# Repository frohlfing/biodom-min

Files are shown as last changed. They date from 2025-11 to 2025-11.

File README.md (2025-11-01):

# Projekt "Biodom Mini" – Ein Hightech-Gewächshaus

Das Ziel ist ein Mini-Gewächshaus für anspruchsvolle Pflanzen, das automatisch für ein tropisches Klima sorgt.

**Features:**

- Künstliche Sonne
- Konstante Temperatur
- Konstante Luftfeuchtigkeit
- Automatische Bewässerung
- Kamera (schießt ein Bild pro Tag für Zeitraffer-Video)
- Display (zeigt aktuelle Werte an)
- Webinterface (über WLAN erreichbar)

## Projektdokumentation

Eine detailliertere technische Dokumentation befindet sich in [Projektdokumentation.md](docs/Projektdokumentation.md).

## Lizenz

Dieses Projekt steht unter der [GPL-3.0-Lizenz](LICENSE).

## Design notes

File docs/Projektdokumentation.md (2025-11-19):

# Projekt "Biodom Mini" – Ein Hightech-Gewächshaus

* **Version:** 1.0.2
* **Datum:** 11.11.2025
* **Autor:** Frank Rohlfing

Das Ziel ist ein Mini-Gewächshaus für anspruchsvolle Pflanzen, das automatisch für ein tropisches Klima sorgt.

**Features:**

- Künstliche Sonne
- Konstante Temperatur
- Konstante Luftfeuchtigkeit
- Automatische Bewässerung
- Kamera (schießt ein Bild pro Tag für Zeitraffer-Video)
- Display (zeigt aktuelle Werte an)
- Webinterface (über WLAN erreichbar)

**Inhaltsverzeichnis**

* [Projekt "Biodom Mini" – Ein Hightech-Gewächshaus](#projekt-biodom-mini--ein-hightech-gewächshaus)
  * [1. Gehäuse](#1-gehäuse)
  * [2. Steuereinheit](#2-steuereinheit)
  * [3. Sensoren](#3-sensoren)
  * [4. Aktoren](#4-aktoren)
  * [5. Sonstige Peripheriegeräte](#5-sonstige-peripheriegeräte)
  * [6. Stromversorgung](#6-stromversorgung)
  * [7. Schaltplan](#7-schaltplan)
  * [8. Programmierung](#8-programmierung)

  * [Anhang](#anhang)

## 1. Gehäuse

### Gewächshaus 

AKERBÄR Gewächshaus 65, anthrazit

[Ikea](https://www.ikea.com/de/de/p/akerbaer-gewaechshaus-drinnen-draussen-anthrazit-20537175/)
29,99 €

Gewächshaus

Maße Gewächshaus

Maße: 65 x 22 (bzw. 13 oben) x 40 cm (B, T, H) 

### Blumenkasten 

Geli Blumenkasten Standard 60 cm

[Obi](https://www.obi.de/p/7331374/geli-blumenkasten-standard-ca-60-cm-anthrazit)
1,65 €

Blumenkasten

Maße: 60 x 18 x 13,7 cm (B, T, H)	

### Behälter für den Teich

Bedingungen: 
* Der Behälter muss eine grade Wand haben, um den Füllstandsensor anbringen zu können.
* Das Material darf aufgrund des Füllstandsensors nicht aus Metall sein (Glas, Kunststoff oder Keramik ist ok).
* Muss in den Blumenkasten passen (max. 12 cm tief, 13 cm hoch).

Ich habe diese Vase im Keller gefunden, passt perfekt:

* Material: Glas
* Außenmaße: 10 x 10 x 10 cm  
* Wandstärke: 4mm

### Bewässerungsset

Bewässerungsschlauch 4/6 mm (passend zur Wasserpumpe)

Bewässerungsset
Bewässerungsset

[Amazon](https://www.amazon.de/gp/product/B0DSP1KB8S)
7,98 €; "Einzelpreis": 3,99 €		

5 m Schlauch, 10 Tropf-Sprinkler, 2 Ventile, Verbinder (reicht locker für 2 Häuschen)

### Elektronik-Box

Kunststoffgehäuse 200 x 120 x 75 mm

Kunststoffgehäuse

[Amazon](https://www.amazon.de/dp/B0DJD3WC1V)
7,99 €

* IP65 (wasserdicht)

In das Gehäuse wird das Mainboard geschraubt. 

### Mainboard

Lochrasterplatine, 160 x 100 mm, blau 

Standard-Platine

[Amazon](https://www.amazon.de/gp/product/B081K7467B)
7,99 €

* Durchkontaktiert, runde Pads
* Rastermaß: 2,54 mm
* 1,6 mm dick

### Klinkenstecker und -Buchsen für die Sensoren (Kamera ausgenommen)

3.5 mm Stereo-Klinkenstecker und -Buchse 

Klinkenstecker und -Buchse

https://www.amazon.de/dp/B09TK2HNKD
6,79 € (10 Stück)

* Muss Stereo sein (3 Pins)!

4 Klinkenbuchsen werden benötigt für:
* Luft
* Bodentemperatur
* Bodenfeuchte
* Wasserstand

**Pinbelegung:**!

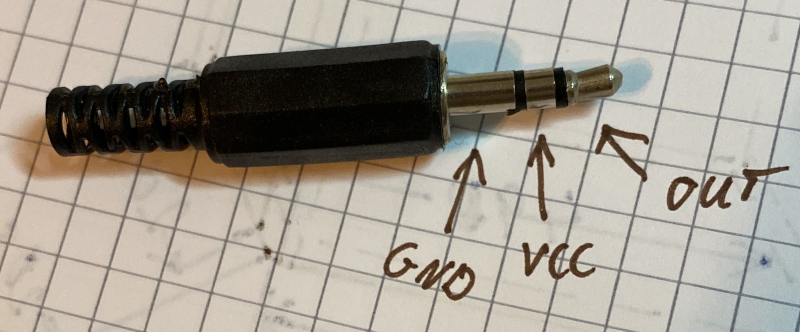
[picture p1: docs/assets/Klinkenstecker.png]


### Hohlstecker und -Buchen für die Aktoren und Stromversorgung

DC Power Jack Buchse und Stecker, 2.1 mm, 2 Polig 

Auch DC-Stecker und DC-Buchse genannt.

DC Buchse

[Amazon](https://www.amazon.de/dp/B07QNWSKN2)
7,49 € (12 Stück)

* Typ: 5.5 x 2.1 mm Buchse (passend zum 5.5x2.1 mm Holstecker des Netzteils)

7 Hohlstecker-Buchsen werden benötigt für:
* Lampe 1
* Lampe 2
* Heizer
* Dunst
* Pumpe
* Lüfter
* DC 12V

**Pinbelegung:**!

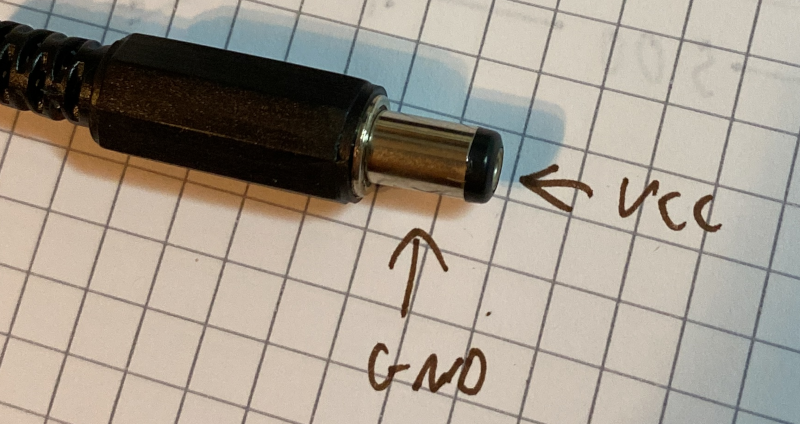
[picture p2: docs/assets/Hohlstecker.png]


### Sonstiges Zubehör

**Stiftleisten und Buchsenleisten zum Einlöten auf die Platine** 

Auch unter "Pinheader" zu finden.

  Stift- und Buchenleisten

  [Amazon](https://www.amazon.de/dp/B0BZH6YZF8)
  10,99 €

**Kabelschlauch, selbstschließend**

Kabelschlauch

6 mm Durchmesser, 3 m: 
[Amazon](https://www.amazon.de/dp/B07FW5H57B)
7,99 €

13 mm Durchmesser, 3 m: 
[Amazon](https://www.amazon.de/dp/B07FW3GTXB)
7,99 €

**Abstandhalter Set**

Abstandhalter

[Amazon](https://www.amazon.de/dp/B0DCS5C7SN)
8,99 €

**Schraubklemmen Set**
Schraubklemmen
[Amazon](https://www.amazon.de/dp/B082ZNRQMJ)
8,99 €

## 2. Steuereinheit

### Mikrocontroller

ESP32-DevKitC V2

ESP32-DevKitC V2

[Amazon](https://www.amazon.de/dp/B074RGW2VQ)
10,99 €

[AZ-Delivery e-Book](https://cdn.shopify.com/s/files/1/1509/1638/files/AZ281_A_18-10_DE_B08BTWJGFX_e699c448-ffc6-4744-8b93-5c9f102d22b0.pdf),  
[Espressif Doku](https://docs.platformio.org/en/latest/boards/espressif32/esp32-c3-devkitc-02.html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),  
[Datasheet](https://cdn.shopify.com/s/files/1/1509/1638/files/ESP_-_32_NodeMCU_Developmentboard_Datenblatt_AZ-Delivery_Vertriebs_GmbH_10f68f6c-a9bb-49c6-a825-07979441739f.pdf)

* Micro-USB-Anschluss
* 38-Pin
* ESP32-WROOM-32-Chip
* CP2102

**Anmerkung:**

Das Modell mit UCD-C macht nur Probleme. Keins meiner UCB-C-Kabel hat funktioniert.

**Pinbelegung:**
<pre>  
                                       ┌────────────────┐
                           +3.3V Out ──┤ 3V3 ESP32  GND ├── GND
                                     ──┤ EN  DevKit G23 ├── GPIO23 SPI_MOSI ──► Kamera + SD-Karte
  Reserve analog./dgl. In ──► GPIO36 ──┤ SP  C V2   G22 ├── GPIO22 I2C_SCL  ──► Kamera + Display + Lichtstärke
       (frei analog./dgl. In) GPIO39 ──┤ SN         TXD ├── GPIO1  (UART0_TX)
    Bodenfeuchte (analog) ──► GPIO34 ──┤ G34        RXD ├── GPIO3  (UART0_RX)
              Wasserstand ──► GPIO35 ──┤ G35        G21 ├── GPIO21 I2C_SDA  ◄─► Kamera + Display + Lichtstärke
         Dunst Relais IN7 ◄── GPIO32 ──┤ G32        GND ├── GND
         Pumpe Relais IN6 ◄── GPIO33 ──┤ G33        G19 ├── GPIO19 SPI_MISO ◄── Kamera + SD-Karte
        Lüfter Relais IN5 ◄── GPIO25 ──┤ G25        G18 ├── GPIO18 SPI_CLK  ──► Kamera + SD-Karte
        Heizer Relais IN4 ◄── GPIO26 ──┤ G26         G5 ├── ──► LED
       Lampe-2 Relais IN3 ◄── GPIO27 ──┤ G27        G17 ├── GPIO17 SPI_CS   ──► Kamera
       Lampe-1 Relais IN2 ◄── GPIO14 ──┤ G14        G16 ├── GPIO16 SPI_CS   ──► SD-Karte
                        (frei, Boot) ──┤ G12         G4 ├── GPIO4           ◄─► Bodentemperatur (One-Wire)
                                 GND ──┤ GND         G0 ├── (frei, Boot)
  Luft (One-Wire-ähnlich) ◄─► GPIO13 ──┤ G13         G2 ├── (frei, Boot)
                                     ──┤ SD2        G15 ├── (frei, Boot)
                                     ──┤ SD3        SD1 ├──
                                     ──┤ CMD        SD0 ├──
                              +5V in ──┤ 5V  [USB]  CLK ├──
                                       └────────────────┘
</pre>

### Relais-Modul

8-Relais-Modul mit Optokoppler, 5V 

Relais
Relais Anschlüsse

[Amazon](https://www.amazon.de/dp/B07CT7SLYQ)
9,59 €

[AZ-Delivery e-Book](https://cdn.shopify.com/s/files/1/1509/1638/files/AZ041_C_9-7_DE_B07CT7SLYQ_b3af212d-3531-46ad-b4fc-e49166c8d2f2.pdf),
[Datasheet](https://cdn.shopify.com/s/files/1/1509/1638/files/8-Relais_Modul_Datenblatt_AZ-Delivery_Vertriebs_GmbH_1f00ff0d-33ca-4546-9ddc-7b2c223f5aa3.pdf)

* Max. DC:  5A, 30V pro Relais
* Maße: 50 x 140 mm

**Anmerkung:**

* Der Jumper zwischen VCC und JD-VCC muss gesteckt sein, da die Relais-Spulen auch von Steuerstromkreis versorgt werden sollen. Ein Stützkondensator wird die Induktionsspitzen beim Schalten abfangen.
* **Achtung, invertierte Logik**: Mit LOW wird das Relais geschaltet, nicht mit HIGH!

**Pinbelegung:**

**Achtung:** Die Pinbelegung sowohl im E-Book und als auch im Datasheet ist nicht korrekt abgebildet: 
NC und NO sind vertauscht. Die Symbole auf dem Modul sind korrekt, sowie hier:

<pre>
         ┌────────────────┐
         │ 8 Relay    NC1 ├──  
         │ Module    Com1 ├──
         │            NO1 ├──
         │            NC2 ├──
         │           Com2 ├── +12V        GND ─O──(schwarz)── GND
         │            NO2 ├────────────────────O──(rot)────── A1: Lampe 1
   GND ──┤ GND        NC3 ├──   
       ─►┤ IN1       Com3 ├── +12V        GND ─O──(schwarz)── GND
GPIO14 ─►┤ IN2        NO3 ├────────────────────O──(rot)────── A2: Lampe 2
GPIO27 ─►┤ IN3        NC4 ├──
GPIO26 ─►┤ IN4       Com4 ├── +12V        GND ─O──(schwarz)── GND
GPIO25 ─►┤ IN5        NO4 ├────────────────────O──(rot)────── A3: Heizer
GPIO33 ─►┤ IN6        NC5 ├──
GPIO32 ──┤ IN7       Com5 ├── +12V        GND ─O──(schwarz)── GND
       ──┤ IN8        NO5 ├────────────────────O──(rot)────── A4: Lüfter
   +5V ──┤ VCC        NC6 ├──
         │           Com6 ├── +12V         GND ─O──(schwarz)── GND
         │            NO6 ├────────────────────O──(rot)────── A5: Pumpe  
         │            NC7 ├──
         │           Com7 ├── +5V        GND ─O──(schwarz)── GND
       ──┤ GND        NO7 ├────────────────────O──(rot)────── A6: Dunst
   Jum- ┌┤ VCC        NC8 ├──  
   per  └┤ JD-VCC    Com8 ├──
         │            NO8 ├──
         └────────────────┘
</pre>

## 3. Sensoren

### S1: Luft (Raumtemperatur und Luftfeuchtigkeit)

Raumtemperatur- und Luftfeuchtigkeitssensormodul AM2302, auch bekannt als DHT22.

Tatsächlich ist AM2302 ein Nachfolgemodel von DHT22 und präziser. 

Der Sensor ist auch "pur" ohne Modul erhältlich. Dann muss zusätzlich ein Pullup-Widerstand (typischerweise 4.7 kΩ bis 10 kΩ) zwischen der Datenleitung und VCC angeschlossen werden. Ich verwende hier das Modul, das den Pullup-Widerstand bereits beinhaltet.

AM2302

[Amazon](https://www.amazon.de/dp/B078SVZB1X)
8,49 €

[AZ-Delivery e-Book](https://cdn.shopify.com/s/files/1/1509/1638/files/AZ073_A10-7_DE_B06XF4TNT9_a2f405a2-b242-44dc-aa26-428bc637eef5.pdf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),
[Datasheet](https://www.makerguides.com/wp-content/uploads/2019/02/DHT22-AM2302-Datasheet.pdf)

**Anmerkung:**

* Das Protokoll für den AM2302ist (One-Wire) ist bidirektional. Demnach darf dieser Sensor nicht an die GPIO 34, 35, 36 oder 39!
* Bei einer Versorgungsspannung von 3.3V darf die Kabellänge nicht größer als 1 Meter sein.

**Pinout:**

| Pin | Bezeichnung | Farbe | Beschreibung |
|-----|---|---|---|
| 1 | + | rot | 3.3V - 5.5V  |  
| 2 | Out | gelb | Daten-Pin |  
| 3 | - | schwarz  | GND | 

**Pinbelegung:**
<pre>
┌────────────────┐
│ AM2302       - ├──(schwarz)─O─── GND 
│ Module     Out ├─────(gelb)─O─►─ GPIO13
│              + ├─►────(rot)─O─── +3.3V
└────────────────┘               
</pre>

**Benötigte Bibliothek:**

* SimpleDHT 1.0.15 by Winlin

### S2: Bodentemperatur

Bodentemperatursensor DS18B20

Dieser Sensor ist wasserdicht, kommt mit 1m-Kabel und Edelstahlhülse.

DS18B20

[Amazon](https://www.amazon.de/dp/B01MZG48OE)
8,29 €	(2 Stück); Einzelpreis: 4,15 €

[AZ-Delivery e-Book](https://cdn.shopify.com/s/files/1/1509/1638/files/AZ079_C_12-8_DE_B01MZG48OE_249c2b9f-7891-4e9a-9169-0dc281f12f11.pdf),
[Datasheet](https://cdn.shopify.com/s/files/1/1509/1638/files/DS18B20_1mCable_datasheet.pdf)

**Anmerkung:**

Das Protokoll für den DS18B20 (One-Wire) ist bidirektional. Demnach darf dieser Sensor nicht an die GPIO 34, 35, 36 oder 39!

**Pinout:**

| Pin  | Bezeichnung | Farbe | Beschreibung |
|---|---|---|---|
| 1 | VCC | rot | 3.3 - 5.5V |  
| 2 | DATA | gelb | Daten-Pin | 
| 3 | GND | schwarz | GND |

**Pull-Up-Widerstand R1 = 4.7 kΩ** 

Wird zwischen dem roten Kabel (VCC) und dem gelben Kabel (DATA) an die Buchsenleiste gelötet.

**Pinbelegung mit Pullup-Widerstand:**
<pre>
┌────────────────┐                   R1=4.7k
│ DS18B20    GND ├──(schwarz)─O────────────────── GND 
│           DATA ├─────(gelb)─O─────┬───────────► GPIO4
│            VCC ├─►────(rot)─O──┐  └─[ R1 ]─┐
└────────────────┘               └───────────┴─── +3.3V
</pre>

**Benötigte Bibliothek:**

* DallasTemperature 4.0.5 by Miles Burton

### S3: Bodenfeuchte

Kapazitiver Bodenfeuchtigkeitssensor v1.2

Auch bekannt als "Capacitive Soil Moisture Sensor v1.2" oder "Hygrometer Module v1.2".

Hygrometer

[Amazon](https://www.amazon.de/dp/B07HJ6N1S4)
6,46 €

[Praxisbericht](https://www.makerguides.com/capacitive-soil-moisture-sensor-with-arduino/), 
[AZ-Delivery e-Book](https://cdn.shopify.com/s/files/1/1509/1638/files/AZ063_A_16-13_DE_B07HJ6N1S4_1746d1f6-6b82-4b8a-bee1-88d83344cb5a.pdf),
[Datasheet](https://cdn.shopify.com/s/files/1/1509/1638/files/Hygrometer_V1.2_Sensor_Modul_Datenblatt_AZ-Delivery_Vertriebs_GmbH.pdf)

* 5V (!)
* Größe: 22 x 97 x 9 mm 
* analoger Ausgang 

**Anmerkung:** 

[Paradisetronic.com](https://www.amazon.de/dp/B08944FNXV) bietet den Sensor für 3.3V an. Dazu müsste aber ein TLC555C oder TLC555I verbaut sein. 
Tatsächlich ist wie bei AZDelivery ein NE555 drauf (minimale Versorgungsspannung von 4.5V lt. Datenblatt). 
Damit ist der Betrieb mit 3.3V nicht möglich oder zumindest kritisch (s. Praxisbericht oder [Kundenrezension](https://www.amazon.de/gp/customer-reviews/R2E7NX4GYVWY0/ref=cm_cr_getr_d_rvw_ttl?ie=UTF8)). 

**Pinout:**

| Pin  | Bezeichnung | Farbe | Beschreibung |
|---|---|---|---|
| 1 | GND | schwarz | GND |  
| 2 | VCC | rot | 5V | 
| 3 | AOUT | gelb | Daten-Pin |

**Anmerkung:**

Der Sensor hat eine Betriebsspannung von 5 V. Die maximale Ausgangsspannung liegt aber deutlich unter 3.3 V. Ein Spannungsteiler ist also nicht erforderlich.

**Pinbelegung:**
<pre>
┌─────────────────┐
│ Capacitive  GND ├──(schwarz)─O─── GND 
│ Hygrometer  VCC ├──────(rot)─O─── +5V
│ v1.2       AOUT ├─►───(gelb)─O─►─ GPIO34
└─────────────────┘
</pre>   

**Messbereich:**

Darüber steht nichts im Datenblatt. Die Werte habe ich experimental ermittelt.

* Komplett trocken (in der Luft): 2080 mV
* Komplett feucht (im Wasser): 800 mV 

**Benötigte Bibliothek:**

(keine Abhängigkeiten)

**Kalibrierung:**

* Weiße Markierung für die Einstecktiefe beachten!

Messung der Rohwerte: 
```
void setup() {
  Serial.begin(115200);  
}

int valMax = 0;
int valMin = 99999; 

void loop() {
  int val = analogRead(34);  
  if (val < valMin) {
    valMin = val;
  }
  if (val > valMax) {
    valMax = val;
  }
  Serial.print("Min:");
  Serial.print(valMin);
  Serial.print(",Max:");
  Serial.print(valMax);
  Serial.print(",Curr:");
  Serial.println(val);
  delay(1000);
}
``` 
 
Die Messung ergibt 
* im Wasser: 995 bis 1055 => unter 1100
* in der Luft: 2642 bis 2734 => über 2500

Der folgende Code verwendet die Rohwerte und ordnet sie einem Bereich von 0 bis 100 % zu:

```
const int valWater = 1100;
const int valAir = 2500;

void setup() {
  Serial.begin(115200);
}

void loop() {
  int val = analogRead(34);
  int percent = map(val, valAir, valWater, 0, 100);
  percent = constrain(percent, 0, 100);
  Serial.println(percent);
  delay(1000);
}
```

### S4: Wasserstand

Berührungsloser Füllstandsensor XKC-Y25-NPN 

XKC-Y25-NPN

[Amazon](https://www.amazon.de/dp/B0C1ZVZF2L)
10,19 €

[Tutorial](https://www.kreativekiste.de/arduino-anschluss-fluessigkeitsstandsensor-xkc-y25-pnp-sps), 
[Datasheet](https://www.nuggetforum.de/media/kunena/attachments/23214/NPN-bb00ea11-07b9-4b43-be78-ce18f0e40b48.pdf)
 
* 5-12 V, 100 mA
* berührungslos, kann Kunststoff-, Glas-, Keramik- und andere nichtmetallische Behälter durchdringen (≤ 20 mm dick)
* wasserdicht
* Ausgang: NPN, digital (LOW bei Wassererkennung)
* Kabellänge: ca. 50 cm
* Pegelfehler: ±1,5 mm

**Pinout:**

| Pin | Bezeichnung | Farbe am Sensor | Farbe am Klinkenstecker | Beschreibung |
|-----|---|---|---|---|
| 1 | VCC | braun | rot | Versorgung (5–12V) |  
| 2 | OUT | gelb | grün | Digitaler Ausgang | 
| 3 | GND | blau | weiß | GND |
| 4 | MODE | schwarz | - | Modus-Umschaltung (wird nicht benötigt)  | 

**Anmerkung:**

* Eventuell sind Schwarz und Gelb vertauscht (OUT = Schwarz, MODE = Gelb)

Pegel am Ausgang:

* Der Sensor wird mit 5 V versorgt, aber das ist in diesem Fall kein Problem für den ESP32. 
	Denn am Ausgang liegen niemals die +5V an: 
	* Wasser erkannt: Er verbindet seinen Ausgang (OUT) mit GND.
	* Kein Wasser: Der Ausgang ist hochohmig (existiert quasi nicht).

**Pull-Up-Widerstand R2 = 10 kΩ**

Wird zwischen +3.3V vom ESP32 und dem gelben Kabel (OUT) an die Buchsenleiste gelötet.

So wird der Pegel auf HIGH (+3.3V) gezogen, wenn Trockenheit erkannt wird.    

**Pinbelegung mit Pullup-Widerstand:**
<pre>
┌────────────────┐                     R2=10k 
│ XKC-Y25    VCC ├────(braun)─O───────────────── +5V   
│ -NPN       OUT ├─►───(gelb)─O─────┬──[ R2 ]─── +3.3V 
│            GND ├─────(blau)─O───┐ └─────────►─ GPIO35    
│           MODE ├──(schwarz)─O   └───────────── GND         
└────────────────┘    
</pre>

**Benötigte Bibliothek:**

(keine Abhängigkeiten)

### S5: Lichtstärke

Lichtsensormodul GY-302 BH1750

Dieser Sensor ist sehr genau und misst das Licht direkt in LUX.

GY-302 BH1750

[Amazon](https://www.amazon.de/dp/B07TKWNGZ4)
5,49 €

[AZ-Delivery e-Book](https://cdn.shopify.com/s/files/1/1509/1638/files/AZ104_A6-9_DE_B07TKWNGZ4.pdf)
[Datasheet](https://cdn.shopify.com/s/files/1/1509/1638/files/GY-302_Licht_Sensor_Modul_Datenblatt_AZ-Delivery_Vertriebs_GmbH.pdf)

* I2C-Schnittstelle (Adresse 0x23 (oder 0x5C, wenn der ADDR-Pin auf HIGH gelegt wird))
* Der IC auf der Platine direkt über dem Schriftzug "BH1750" ist das lichtempfindliche Bauteil. 
**Pinout:**

| Pin | Bezeichnung | Farbe | Beschreibung |
|-----|---|---|---|
| 1 | VCC | rot | 3.3V, 5V |  
| 2 | GND | schwarz | GND | 
| 3 | SCL | braun | I2C Serial Clock (input) | 
| 4 | SDA | orange  | I2C Serial Data (bidirectional) |  
| 5 | ADDR | gelb | Geräteadresse (input) |  

**Pinbelegung:**
<pre>
┌────────────────┐
│ GY-302     VDD ├──────(rot)─O── +3.3V
│ BH1750     GND ├──(schwarz)─O── GND
│            SCL ├────(braun)─O─◄─ GPIO22
│            SDA ├───(orange)─O◄─► GPIO21 
│           ADDR ├─────(gelb)─O──
└────────────────┘
</pre>

**Anmerkung:**

Da kein anderes I2C-Gerät die Adresse 0x23 verwendet, wird ADDR nicht benötigt.

**Benötigte Bibliothek:**

* BH1750 1.3.0 by Christofer Laws

### S6: Reserve

Der Analog-/Digitaleingang GPIO36 wird über eine Stiftleiste zugänglich gemacht. Er ist noch nicht verplant.

Als Beispiel könnte ein Fotowiderstand (auch Fotozelle oder LDR (Licht-Dependent Resistor) genannt) angeschlossen werden:

Fotowiderstand LDR5528

[Amazon](https://www.amazon.de/dp/B089YNCYG4)
4,49 € (10 Stück), Einzelpreis: 0,49 €

[AZ-Delivery e-Book](https://cdn.shopify.com/s/files/1/1509/1638/files/AZ098_B_16-1_DE_B089YNCYG4_ff124573-82f8-46ba-8411-8660b6462697.pdf)
[Datasheet](https://cdn.shopify.com/s/files/1/1509/1638/files/Fotowiderstand_Photo_Resistor_Dioden_150V_5mm_LDR5528_GL5528_5528_Datenblatt_AZ-Delivery_Vertriebs_GmbH.pdf)

5mm
* 0.5 - 200 kΩ
* Maximale Spannung: 150 V
* Maximale Leistung: 100 mW

Der Fotowiderstand ist lichtabhängig. Je mehr Licht auf die Oberfläche fällt, desto geringer ist sein Widerstand.

Der Sensor wird zusammen mit einem Widerstand als Spannungsteiler an einem analogen Eingang des ESP32 geschaltet. 
Dieser wandelt die Spannung in ganzzahlige Werte zw. 0 (dunkel) und 4049 (hell) um, die als ADC-Wert oder Analogwert bezeichnet werden.

<pre>
                    ↙↙
GND ───[ R3 ]──┬──[ LDR ]──── +3.3V
        10 kΩ  │  LDR5528
               └───────────►─ GPIO36
</pre>

**Benötigte Bibliothek:**

(keine Abhängigkeiten)

## 4. Aktoren

### A1, A2: Lampe

LED Grow Light 12V/60W, Vollspektrum, 4:1, IP65

LED-Streifen

[Amazon](https://www.amazon.de/gp/product/B076D3GCH4)
18,99 €

* 12V, 60W
* Rot:Blau = 4:1
* Vollspektrum
* IP65 (wasserdicht)
* 5m-Streifen (1 cm breit) mit 300 LEDs (SMD 5050)
* Hersteller: Tesfish

12V/60W = 5A (lt. Hersteller) -> Damit ist das Limit für ein Relais des Relais-Moduls erreicht. Daher teile ich den 
5m-Streifen in zwei Hälften, um die Last auf zwei Relais verteilen zu können. 
Außerdem könnte ich das Licht so in zwei Helligkeitsstufen schalten.  

**Aufteilung des LED-Streifens in 2 Lampen:**
<pre>
            O─▓▓▓▓▓▓▓▓▓▓▓▓▓▓▓▓▓▓▓▓▓▓▓▓▓▓▓▓▓▓▓─O┐
          ┌─O─░░░░░░░░░░░░░░░░░░░░░░░░░░░░░░░─O│┐
          │┌O─▓▓▓▓▓▓▓▓▓▓▓▓▓▓▓▓▓▓▓▓▓▓▓▓▓▓▓▓▓▓▓─O┘│
Lampe 1 O─┼─O─░░░░░░░░░░░░░░░  ░░░░░░░░░░░░░░─O─┘
Lampe 2 O─│┼O─▓▓▓▓▓▓▓▓▓▓▓▓▓▓▓  ▓▓▓▓▓▓▓▓▓▓▓▓▓▓─O┐
          └─O─░░░░░░░░░░░░░░░░░░░░░░░░░░░░░░░─O│┐
           └O─▓▓▓▓▓▓▓▓▓▓▓▓▓▓▓▓▓▓▓▓▓▓▓▓▓▓▓▓▓▓▓─O┘│
            O─░░░░░░░░░░░░░░░░░░░░░░░░░░░░░░░─O─┘
            <-------------- 60cm ------------->
</pre>

**UPDATE: Tatsächliche Leistung (Messwerte):**

* Leistung pro Streifenhälfte (2,5m): Spannung: 12 V, Strom: 2 A -> Reale Leistung: P = U * I = 12 V * 2 A = 24 Watt
* Leistung des gesamten Streifens (2 x 2,5m): Spannung: 11.9 V, Strom: 3.8 A -> Reale Gesamtleistung: P = 11.9 V * 3.8 A ≈ 45 Watt

Der gemessene Strom ist unter 4A, es würde 1 Relais reichen. (Sicherheitsmarge von 20 % ist ok). 
Aber dann kann ich nicht mehr zwei Helligkeitsstufen schalten. 

**Pinbelegung:**
<pre>
┌────────────────┐
│ LED Grow  +12V ├──────(rot)─O── Relais IN2
│ Light 1        │
│ 30W        GND ├──(schwarz)─O── GND
└────────────────┘
┌────────────────┐
│ LED Grow  +12V ├──────(rot)─O── Relais IN3
│ Light 2        │
│ 30W        GND ├──(schwarz)─O── GND
└────────────────┘
</pre>

**Passt die Lampe zum Gehäuse?**

**Ideale Lichtmenge (PPFD):**

* Die Lichtmenge wird in der Pflanzenwissenschaft in PPFD (Photosynthetic Photon Flux Density) gemessen. 
* Die Einheit ist µmol/m²/s. Der Wert gibt an, wie viele Photonen pro Sekunde auf einen Quadratmeter treffen. 
* Typische PPFD-Werte:
	* Cannabis:
		* Keimlinge/Stecklinge: 150 - 300 µmol/m²/s
		* Vegetatives Wachstum: 300 - 600 µmol/m²/s
		* Blütephase: 600 - 1.000 µmol/m²/s
	* Zitrone, Mango, Avocado: 
		* Wachstum (Jungpflanze): 300 - 500 µmol/m²/s
		* Fruchtbildung: > 700 µmol/m²/s.
	* Allround-Gewächshaus:
		* ≈ 400-600 µmol/m²/s

**Die Lichtmenge der Lampe:**

* **Leistung der Lampe:** Die Lampe wird mit 60W beworben. Laut [Kundenrezension](https://www.amazon.de/gp/customer-reviews/RP3TF4WHOI91K/ref=cm_cr_dp_d_rvw_ttl?ie=UTF8) leistet die Lampe nur 40 W. 

* **Effizienz der Lampe:** Die Effizienz einer Lampe wird in µmol/Joule angegeben. Sie sagt aus, wie viele Licht-Photonen (µmol) pro Wattsekunde (Joule) erzeugt werden.
Typische Werte für SMD 5050 Grow-LEDs, aus denen die Lampe besteht, liegen bei 1,5 bis 1,8 µmol/Joule. 

* **Pflanzenfläche:** Das AKERBÄR Gewächshaus hat unten eine Fläche von 0,60 x 0,2 m = 0,12 m².

* Jetzt können wir rechnen:

	* Gesamter Photonenfluss (PPF): Wie viele Photonen produziert die 40W-Lampe insgesamt pro Sekunde?
  
		PPF (µmol/s) = Leistung (Watt) * Effizienz (µmol/J)
	
		* Min: 40 W * 1.5 µmol/J = 60 µmol/s
		* Max: 40 W * 1.8 µmol/J = 72 µmol/s		

	* PPFD auf der Fläche - Jetzt verteilen wir diese Gesamtmenge an Photonen auf unsere Anbaufläche.
  
		PPFD (µmol/m²/s) = PPF (µmol/s) / Fläche (m²)

		* Min: 60 µmol/s / 0,12 m² = 500 µmol/m²/s
		* Max: 72 µmol/s / 0,12 m² = 600 µmol/m²/s

=> Die Lampe passt perfekt zum Gehäuse!

### A3: Heizer

Silikon-Heizmatte, 12V/12W, 60°C

Heizmatte

[Amazon](https://www.amazon.de/dp/B09VB1Q2G4)
7,19 €

* 12V, 12W
* bis 60°C
* 10 x 12 x 1,5cm

Der tatsächliche Strombedarf beträgt 930 mA (gemessen).

**Pinbelegung:**
<pre>
┌────────────────┐
│ Heating   +12V ├─────O── Relais IN4 
│ max. 60°C      │
│ 12W        GND ├─────O── GND
└────────────────┘
</pre>

### A4: Lüfter

PC-Lüfter, Silent, 12V, 8.5 CFM, 50 mm

Super Silent Fan

[Amazon](https://www.amazon.de/dp/B01HTN8XZE)
6,94 €;

* 12 V, 50 mA
* 50 x 50 mm
* 8,5 CFM
* 17,5 dB
* 3500 Umdrehungen pro Minute
 
**Pinout:**

| Pin | Bezeichnung | Farbe | Beschreibung |
|-----|---|---|---|
| 1 | +12V | rot | Versorgung |  
| 2 | GND | schwarz | GND |  
| 3 | RPM | gelb | Tachosignal  | 

**Anmerkung:**

Das gelbe Kabel mit der Bezeichnung "RPM" (Revolutions Per Minute) wird nicht benötigt. 
Es liefert ein "Tachosignal" (typischerweise 2 Pulse pro Umdrehung). Man könnte damit z.B. per Mikrocontroller prüfen, ob der Lüfter läuft oder blockiert ist.

**Pinbelegung:**
<pre>
┌────────────────┐
│ Fan       +12V ├──────(rot)─O── Relais IN5 
│                │
│ 0.6W       GND ├──(schwarz)─O── GND
└────────────────┘
</pre>

**Montage des Lüfters:**

[Montageanleitung des PC-Lüfters](https://m.media-amazon.com/images/I/91Py5fJkHrL.pdf)

Pflanzen verbrauchen CO₂ und geben Sauerstoff ab. Die "verbrauchte" und feuchte Luft steigt auf und sammelt sich im oberen Bereich des Gewächshauses.
Die Luft muss also von unten nach oben zirkulieren. 

Der Lüfter wird die Luft nach außen pusten und muss daher oben angebracht werden.

**Reicht die Leistung des Lüfters aus?**

Wie schnell der gewählte Lüfter die gesamte Luft im Gewächshaus austauschen kann. 
Ein guter Wert für ein kleines Gewächshaus liegt bei einer Luftaustauschrate von mindestens 1-mal pro Minute.

* Der Luftstrom der Lüfter wird in CFM (Cubic Feet per Minute) angegeben: 1 CFM ≈ 0,0283 m³/min

* Der ausgewählte PC-Lüfter pustet 8,5 CFM = 8.5 * 0,0283 m³/min = 0,24055 m³/min

* Das AKERBÄR Gewächshaus hat ein Volumen von 0,65 m * (0,22 m + 0,13 m)/2 * 0,40 m = 0,0455 m³.

* Die Luftaustauschrate ist somit 0,24055 m³/min / 0,0455 m³ ≈ **5,3-mal pro Minute**

=> Der Lüfter reicht völlig aus.

### A5: Pumpe

Mini 370 Membranpumpe, 12V

Wasserpumpe
Wasserpumpe

[Amazon](https://www.amazon.de/dp/B0DX5PVTBQ)
8,98 €

Wird mit 1 m Schlauch geliefert (5 mm innen).

* max. 300mA
* Saughöhe: 2m
* Durchflussmenge: 700ml

**Pinbelegung:**
<pre>
┌────────────────┐
│ Mini      +12V ├──────(rot)─O── Relais IN6 
│ Pump           │
│ 3.6W       GND ├──(schwarz)─O── GND
└────────────────┘
</pre>

### A6: Dunst

Ultraschall-Vernebler, 5V/5W

Vernebler
Vernebler Maße

[Amazon](https://www.amazon.de/gp/product/B0FM2FZD4Z)
12,49 €		

* 5V, 5W
* 1,4m Kabel
* 4,7 x 2,5 cm (B, H)
* Wassermangelschutz
* LED Farbwechsel

USB-Stecker abknipsen und Klinkenstecker anlöten.
Kabeladern:
* Braune = VCC
* Weiß = GND

**Pinbelegung:**
<pre>
┌────────────────┐
│ Mist       +5V ├──────(rot)─O── Relais IN7 
│ Maker       D- ├─────(weiß)─O── 
│ 5W          D+ ├─────(grün)─O── 
│            GND ├──(schwarz)─O── GND
└────────────────┘
</pre>

## 5. Sonstige Peripheriegeräte

### Z1: Display

1.3 Zoll OLED Display, SSH1106

Display

[Amazon](https://www.amazon.de/dp/B078J78R45)
8,49 €

[AZ-Delivery e-Book](https://cdn.shopify.com/s/files/1/1509/1638/files/AZ003_A_1-6_DE_B078J78R45_1.pdf?v=1721030497), 
[Datasheet](https://cdn.shopify.com/s/files/1/1509/1638/files/1_3_Zoll_Display_Datenblatt_AZ-Delivery_Vertriebs_GmbH_rev.pdf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)

* 3.3V, 5V
* I2C-Schnittstelle (Adresse 0x3C)
* 128 x 64 Pixel
* Chip: SSH1106 
* Platine: 36 x 34 mm

**Pinout:**

| Pin | Bezeichnung | Farbe | Beschreibung |
|-----|---|---|---|
| 1 | VDD | grün  | 3.3V, 5V |  
| 2 | GND | blau  | GND | 
| 3 | SCK | lila  | I2C Serial Clock (input) | 
| 4 | SDA | grau  | I2C Serial Data (bidirectional) |  

**Pinbelegung:**
<pre>
┌────────────────┐
│ 1.3″       VDD ├──────(rot)─O── +3.3V
│ OLED       GND ├──(schwarz)─O── GND
│ Display    SCK ├────(braun)─O─◄─ GPIO22
│ SSH1106    SDA ├───(orange)─O◄─► GPIO21 
└────────────────┘
</pre>

**Benötigte Bibliothek:**

U8g2 2.35.30 by oliver

### Z2: SD-Kartenleser

MicroSD SPI Kartenleser, 3.3V 

Dies ist ein MicroSD-Kartenlesemodul.

Kartenleser
Kartenleser Pins

[Amazon](https://www.amazon.de/gp/product/B0DQZFBCST)
4,29 € (3 Stück); Einzelpreis: 1,43 €

Auf der Amazon-Webseite ist die Versorgungsspannung falsch angegeben. Richtig ist 3.3V.  

[AZ-Delivery e-Book](https://cdn.shopify.com/s/files/1/1509/1638/files/AZ234_C_10-4_DE_B06X1DX5WS_ec398a85-2534-4b15-9f3e-1d3a37b6ce96.pdf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), 

* 3.3V
* SPI-Schnittstelle
* 0,2 bis 200 mA
* gerade Pins!
* Platinengröße: 17,9 x 17,9 mm

**Pinout:**

| Pin | Bezeichnung | Beschreibung |
|-----|---|---|
| 1 | 3v3 | 3.3V |  
| 2 | CS | SPI Chip Select (input) |  
| 3 | MOSI | SPI Master Output Slave Input (input)  |  
| 4 | CLK | SPI Serial Clock (input) | 
| 5 | MISO | SPI Master Input Slave Output (output) | 
| 6 | GND | GND | 

**Pinbelegung:**
<pre>
┌────────────────┐
│ MicroSD    GND ├───O─── GND
│ SPI       MISO ├───O─►─ GPIO19
│ Module     CLK ├───O─◄─ GPIO18
│           MOSI ├───O─◄─ GPIO23 
│             CS ├───O─◄─ GPIO16 
│            3v3 ├───O─── +3.3V
└────────────────┘
 </pre>

**Speicherkarte:**

SanDisk Ultra 32 GB microSDHC, Class 10, U1

Speicherkarte

[Amazon](https://www.amazon.de/dp/B08HVWJM8C)
7,78 €

* MicroSD (bis 2 GB) und MicroSDHC (4 bis 32 GB) funktionieren mit SPI.
* Geschwindigkeitsklasse: C10 ist Standard für Arduino/ESP32-Projekte (Schreibgeschwindigkeit: mind. 10 MB/s)
* Bus-Typ: UHS-I (U1 oder U3)
* Hersteller: SanDisk (Kingston oder Transcend wäre auch ok)

Die Karte sollte FAT32-formatiert sein.

**4 GB SD-Karte Class 4. vs. 32 GB HC Class 10**

Ich habe noch eine alte 4 GB SD-Karte Class 4. Wie lang reicht die Karte, wenn pro Stunde ein Bild geschossen wird? 
Wie schnell ist sie in der Praxis?

* 93 % einer SD-Karte sind durchschnittlich praktisch nutzbar.
* Die höchste Auflösung der ArduCAM-Kamera ist 1600 x 1200 Pixel. Die Bilder werden im JPEG-Format gespeichert. Ich schätze 600 KB durchschnittlich.  

Es folgt:
* 4 GB: 4 GB * 0,93 * 1024 * 1024 / 600 KB = ≈ 6500 Bilder => 6500 / 24 ≈ **270 Tage**
* 32 GB: 32 GB * 0,93 * 1024 * 1024 / 600 KB = ≈ 52000 Bilder => 52000 / 24 / 365 ≈ **6 Jahre**

Theoretische Schreibgeschwindigkeit pro Bild:
* Class 4 (min. 4 MB/s): 0.6 MB / 4 MB/s = 150 ms. 
* Class 10 (min. 14 MB/s): 0.6 MB / 10 MB/s = 60 ms.

In der Realität ist der Prozess durch den ESP32 und die SPI-Kommunikation limitiert. 
Der gesamte Vorgang (Auslesen von der Kamera + Schreiben auf die Karte) wird vermutlich eher bei 1 bis 1,5 Sekunden liegen.

### Z3: Kamera

ArduCAM Mini 2MP Plus (mit OV2640-Chip)

ArduCAM
ArduCAM Anschlüsse

[BotLand](https://botland.de/kameras-fur-arduino-und-raspberry-pi/6556-arducam-mini-ov2640-2mpx-1600x1200px-60fps-spi-kameramodul-fur-arduino--5904422358242.html)
28,86 €

[User Guide](https://cdn.arducam.com/downloads/shields/ArduCAM_Mini_2MP_Camera_Shield_DS.pdf), 
[Hardware Application Note](https://www.uctronics.com/download/Amazon/ArduCAM_Mini_2MP_Camera_Shield_Hardware_Application_Note.pdf),
[Software Application Note](https://blog.arducam.com/downloads/shields/ArduCAM_Camera_Shield_Software_Application_Note.pdf)

* Sensor: OV2640
* SPI-Interface für Befehle und Kameradaten
* I2C-Interface für die Konfiguration (Adresse 0x60 für Write und 0x61 für Read)
* 3.3 - 5 V
* 20 - 70 mA 
* Größe: 34.1 x 24,4 mm
* Auflösung: 2 Megapixel, 1600 x 1200 px 
* 60 fpsm max. 8 MHz
* Output-Format: JPEG RGB

**Anmerkung:**

Ein SPI-Kabel muss kurz gehalten werden. Die mit Jumper-Kabel (Dupont) empfohlene max. Kabellänge beträgt 20 cm.
Mit geschirmtem Kabel und reduziertem Takt (1–2 MHz) sind 50 cm möglich. 

Tipps für eine stabile SPI-Verbindung:

* SCLK mit GND verdrillen → reduziert EM-Störungen
* MISO mit GND verdrillen → schützt das empfindlichste Signal
* Jede zweite Leitung auf GND bei Flachbandkabel
* Pull-Up-Widerstände an CS und MISO können helfen
* Serienwiderstand (100 Ω) direkt am Mikrocontroller-Ausgang → reduziert Reflexionen

**Warum die relative teure SPI-ArduCAM-Kamera?**

* Die meisten günstigen Kameramodule (auch die auf dem ESP32-CAM) verwenden eine DVP-Schnittstelle (Digital Video Port).
die ca. 16 GPIO-Pins belegt (also fast alle verfügbaren). Die ArduCAM belegt dagegen nur 6 Pins (4 für die SPI und 2 für I2C). 
 
**Pinout:**

| Pin | Bezeichnung | Farbe | Beschreibung |
|-----|---|---|---|
| 1 | CS | schwarz | SPI Chip Select (input). Auswahl eines Geräts auf dem SPI-Bus, aktiviert durch den Low-Zustand. |  
| 2 | MOSI | weiß | SPI Master Output Slave Input (input). Die Ausgangsdatenleitung des SPI-Busses. |  
| 3 | MISO | grau | SPI Master Input Slave Output (output). Eingangsdatenleitung des SPI-Busses. | 
| 4 | SCK | lila | SPI Serial Clock (input). Taktleitung des SPI-Busses. | 
| 5 | GND | blau | GND | 
| 6 | VCC | grün | 3.3V - 5V |  
| 7 | SDA | gelb | Two-Wire Serial Interface Data I/O (bidirectional). Die Ausgangsdatenleitung des I2C-Busses. |  
| 8 | SCL | orange  | Two-Wire Serial Interface Clock (input). Die Taktleitung des I2C-Busses. | 

**Pinbelegung:**
<pre>
┌────────────────┐
│ ArduCAM    SCL ├─◄───(orange)─O─── GPIO22
│ Mini 2MP   SDA ├◄─►────(gelb)─O─── GPIO21
│ Plus,      VCC ├───────(grün)─O─── +3.3V
│ OV2640     GND ├───────(blau)─O─── GND
│            SCK ├─◄─────(lila)─O─── GPIO18
│           MISO ├─►─────(grau)─O─── GPIO19
│           MOSI ├─◄─────(weiß)─O─►─ GPIO23
│             CS ├─◄──(schwarz)─O─── GPIO17 
└────────────────┘        
 </pre>

**Benötigte Bibliothek:**

[Arducam_mini 1.0.1 by Arducam](https://github.com/ArduCAM/Arducam_mini)

Leider ist die Bibliothek so konzipiert, dass die Datei ./Arduino/libraries/Arducam_mini/src/memorysaver.h für die jeweilige Hardware angepasst werden muss. Für meine Kamera muss diese Definition einkommentiert werden:
	#define OV2640_MINI_2MP_PLUS

### Z4: LED

Leuchtdiode 3mm, rot 

Nützlich zum Debuggen

Das längere Beinchen ist der Pluspol.

**Pinbelegung mit Vorwiderstand:**

<pre>
                      ↗↗     
GPIO5 ─▶───[ R2 ]─────▶├───── GND
            330 Ω    LED1
</pre>

## 6. Stromversorgung

### P1: Spannungswandler 12V zu 5V

Step-Down-Module XL4015, 5 A

Step-Down-Modul

[Amazon](https://www.amazon.de/dp/B07VQCXDTC)
9,99 €	(3 Stück); Einzelpreis:	3,33 €

[AZ-Delivery e-Book](https://cdn.shopify.com/s/files/1/1509/1638/files/AZ233_C_9-4_DE_B07SRXR1VT_7e75912c-950c-49d9-aeb2-2b6e195245f1.pdf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),
[Datasheet](https://www.xlsemi.com/datasheet/XL4015-EN.pdf)

**Übersetzungsfehler im E-Book:** "Einstellbare Eingangsspannung" muss heißen "Einstellbare Ausgangsspannung" (orig.: "Output Voltage is Adjustable")
 
* von 8V-36V zu 1,25V-32V einstellbar, max. 5A
* Arbeitstemperatur: -40 ℃ bis +85 ℃
* Übertemperaturschutz (thermische Abschaltfunktion)
* Größe: 54 x 23 x 18 mm (L x B x H)
* XL4015-Chip

**Pinbelegung:**
<pre>
                   ┌────────────────┐
Netzteil DC +12V ──┤ IN+       OUT+ ├──┬──────────────────── ESP32 +5V
                   │  XL4015 Module │  └─⁺▌|─┐ C1: 470µF
             GND ──┤ IN.       OUT- ├────────┴────────────── GND
                   └────────────────┘
</pre>

**Stützkondensator C1**:

C1: Elko 470µF, 16V

Generell ist ein Stützkondensator zu empfehlen, dieser schützt vor Spannungseinbrüchen. 
Erst recht, wenn ein Relais eingesetzt wird, dessen JD-VCC-Jumper gesteckt ist.

Wird so nah wie möglich am Ausgang des Spannungswandlers gelötet.
Das längere Beinchen und der Pin ohne Markierung auf dem Gehäuse ist PLUS (+).
 
**Anmerkung:**

In- und Out-Pin ist dasselbe Potenzial. 

Die Ausgangsspannung muss auf **5 Volt** eingestellt werden!

### Netzteil

12V Steckernetzteil Adapter, 120W

Netzteil

[Amazon](https://www.amazon.de/gp/product/B0DBL4FV6C)
11,99 €

5.5x2.1 mm DC-Holstecker

**Benötigte Leistung / max. Stromaufnahme:**

5V-Komponenten (über Spannungswandler):

* ESP32-DevKitC C: 0,2 – 0,3A (je nach WLAN-Last)
* ArduCAM (SPI): ca. 0,1A (bei Kameraaufnahme)
* SD-Kartenleser (SPI): ca. 0,05A (nur bei Zugriff)
* OLED Display: ca. 0,02A (sehr gering)
* AM2302-Modul: ca. 0,002A (vernachlässigbar)
* DS18B20: ca. 0,002A (vernachlässigbar)
* Hygrometer-Modul: ca. 0,005–0,01 A (gering)
* XKC-Y25-NPN: ca. 0,1 A (bei Aktivierung)
* Ultraschall-Vernebler: ca. 1,0 A (Hauptlast auf 5V)

=> Summe worst case: ca. 1,6 A für 5V-Komponenten

Der Spannungswandler liefert bis zu 5A, also reichlich Reserve.

12V-Komponenten:

* LED Grow Light (5m, 60W): ca. 60W → 5,0A (Hauptlast, Dauerbetrieb)
* Heizmatte (12W):	12W → 1,0A (Dauerlast)
* 2x PC-Lüfter: ca. 0,1A gesamt
* Wasserpumpe Mini: max. 0,3A (Kurzzeitbetrieb)
* Relais-Modul (8-Kanal, 6 im Gebrauch): ca. 0,3A (50mA pro Relais)	(nur wenn alle Relais gleichzeitig anziehen)

=> Summe worst case: ca. 6,7 A für 12V-Komponenten

Max. Gesamtlast am Netzteil: **ca. 8,3 A**

Das 12V-Netzteil liefert 10 A, also sind ca. 1,7 A Reserve. Das ist knapp, aber im grünen Bereich.
 
## 7. Schaltplan

Den Sachaltplan habe ich mit KiCad 9.0 erstellt.

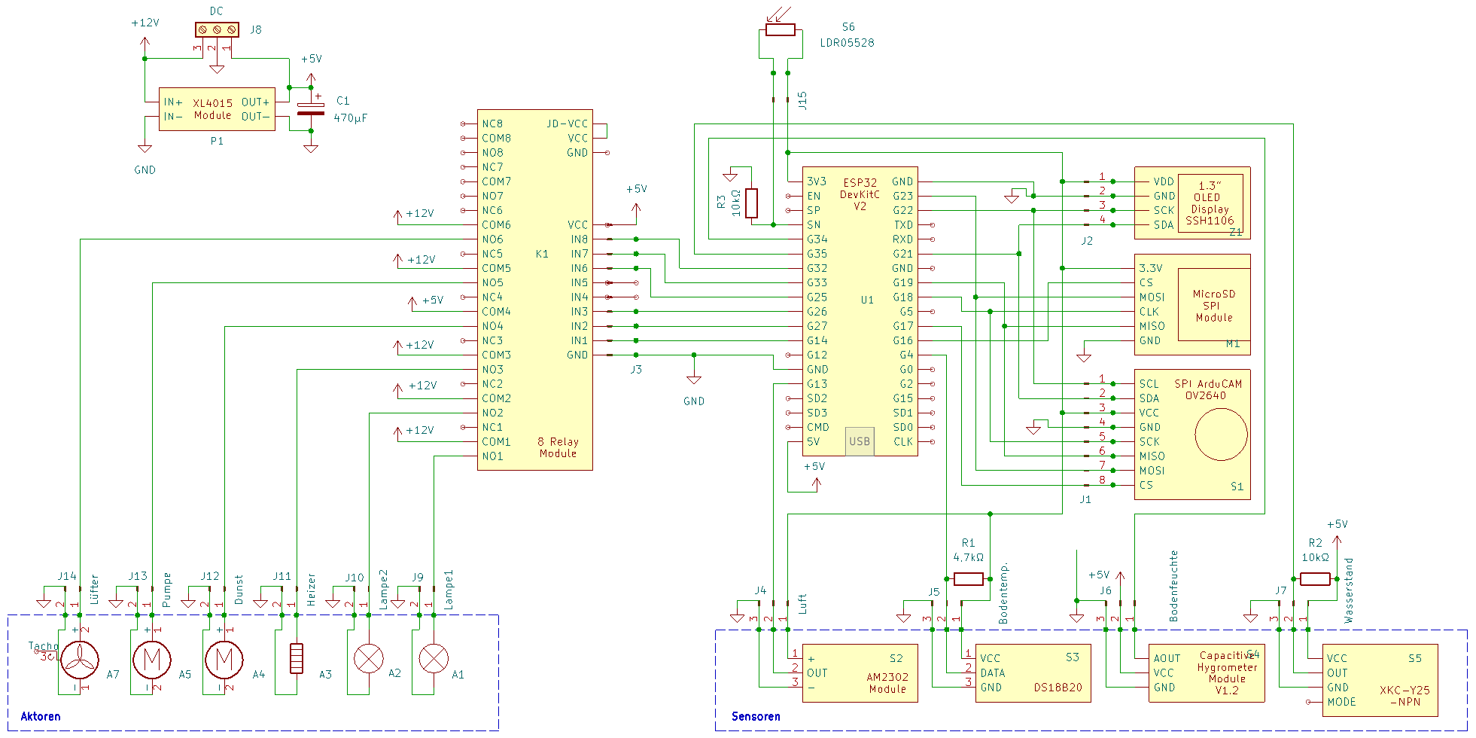
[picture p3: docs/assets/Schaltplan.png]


### Leiterplatten-Entwurf

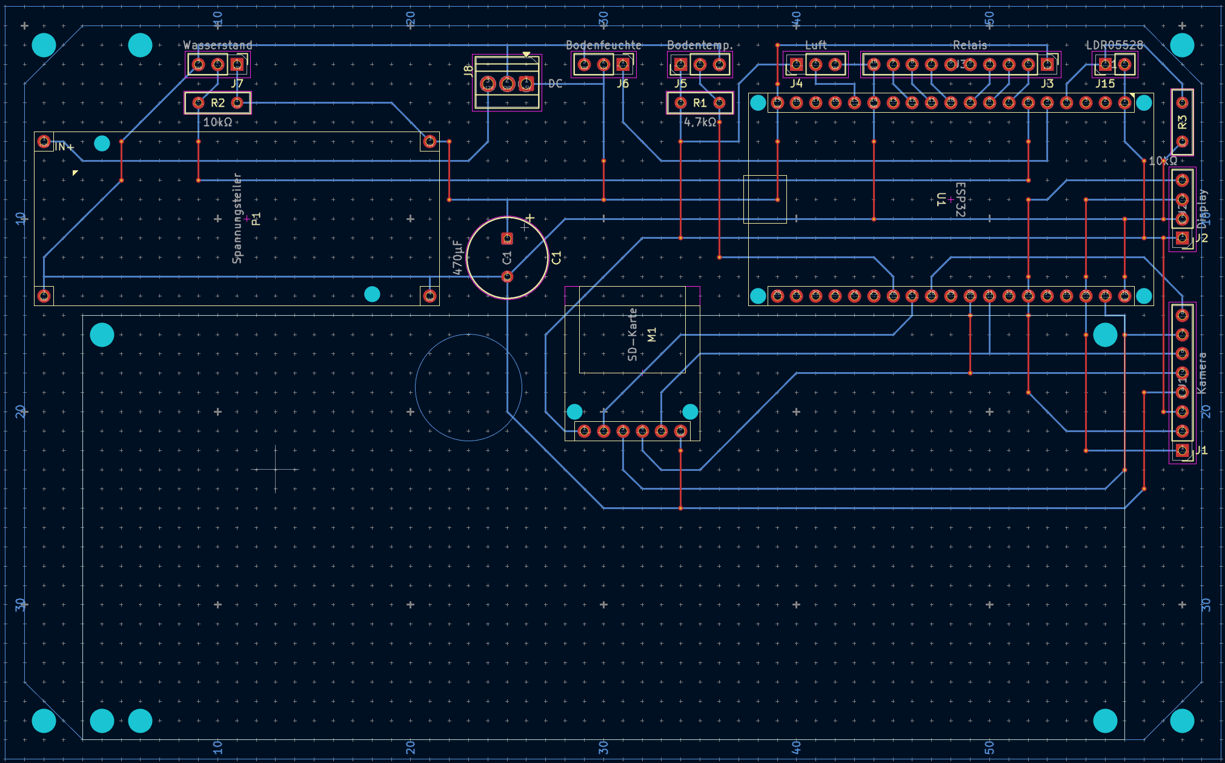
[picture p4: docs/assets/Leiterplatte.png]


## 8. Programmierung

### Entwicklungsumgebung / Technologie-Stack

* PlatformUI mit VS Code
* ArduinoIDE (nur für den erster schneller Funktionstest und Proof Of Concepts, die Sketches liegen im Verzeichnis `sketches`)
* ESP-Prog für das Debuggen (sofern nötig)
* Webinterface via Websocket (Frontend mit HTML, CSS, Vanilla JS, Single-Page)
* OTA-Upload (Over-The-Air) für das Produktivsystem

Mit der PlatformUI wird für jedes Bauteil eine lokale Bibliothek bereitgestellt und ausführlich dokumentiert.

Es wird auch jeweils eine Bibliothek für das Webinterface, für OTA und für den Zugriff auf die Sollwerte (als persistentes Dictionary o.ä.) bereitgestellt (um `main.cpp` möglichst schlank halten zu können). 

### Steuerungslogik

Die Steuerung soll dafür sorgen, dass ein gleichmäßiges Klima für die Pflanzen im Gewächshaus herrscht. 

Die dafür verfügbaren Sensoren und die zu steuernden Aktoren sind hier nochmal kurz zusammengefasst: 

**Sensoren:**

| Präfix | Name | Spezifikation | GPIO |
|---|---|---|---|
| S1 | Raumtemperatur- und Luftfeuchtigkeitssensor | AM2302 Module | GPIO13 | 
| S2 | Bodentemperatursensor | DS18B20 | GPIO4  |
| S3 | Bodenfeuchtigkeitssensor | Capacitive Soil Sensor v1.2 | GPIO34 |
| S4 | Füllstandsensor | XKC-Y25-NPN | GPIO35 |
| S5 | Lichtsensor | GY-302 BH1750 | (I2C)  |

**Aktoren:**

| Präfix | Name | GPIO |
|---|---|---|
| A1 | Lampe 1 | GPIO14 | 
| A2 | Lampe 2 | GPIO27 |
| A3 | Heizer | GPIO26 |
| A4 | Lüfter | GPIO25 |
| A5 | Pumpe | GPIO33 |
| A6 | Vernebler | GPIO32 |

**Sonstige Peripheriegeräte:**

| Präfix | Name | Spezifikation | GPIO |
|---|---|---|---|
| Z1 | Display | 1.3 Zoll OLED Display, SSH1106 | (I2C) |
| Z2 | SD-Kartenleser | MicroSD SPI Kartenleser | CS: GPIO16 |
| Z3 | Kamera | ArduCAM Mini 2MP Plus, OV2640  | CS: GPIO17 |
| Z4 | LED | LED 3mm, rot | GPIO5 |

Es wird folgende Steuerungslogik programmiert (in `main.cpp`):

*   **Lichtsteuerung (A1 und A2):**  
Die Lampen können grundsätzlich nur innerhalb eines festgelegten Zeitfensters aktiv werden, das durch `LIGHT_ON_HOUR` (Einschaltzeit) und `LIGHT_OFF_HOUR` (Ausschaltzeit) definiert ist. Außerhalb dieser Zeit bleiben die Lampen immer aus. Innerhalb des Zeitfensters misst der Lichtsensor (S5) kontinuierlich das Tageslicht. Basierend auf den Schwellwerten `LIGHT_LUX_THRESHOLD_BRIGHT` und `LIGHT_LUX_THRESHOLD_DARK` wird die künstliche Beleuchtung dynamisch angepasst:
    *   **Mittleres Tageslicht:** Wenn das Tageslicht den mittleren Schwellwert (`_DARK`) überschreitet, reicht eine Lampe, die andere wird ausgeschaltet.
    *   **Helles Tageslicht:** Wenn das Tageslicht den oberen Schwellwert (`_BRIGHT`) überschreitet, werden beide Lampen ausgeschaltet.
    *   Ansonsten werden beide Lampen eingeschaltet.

*   **Heizungssteuerung (A3):**  
Die Heizmatte wird aktiviert, wenn die **Bodentemperatur (S2)** unter den Zielwert `SOIL_TEMPERATUR_TARGET` fällt. Um ein ständiges An- und Ausschalten (Flattern) zu verhindern, wird eine Hysterese implementiert: Die Heizung schaltet sich erst wieder aus, wenn die Temperatur den Zielwert um 0.5 °C überschreitet.

*   **Lüftersteuerung (A4):**
Der Lüfter wird aktiviert, wenn die **Raumtemperatur (S1)** den Schwellwert `AIR_TEMPERATUR_THRESHOLD_HIGH` überschreitet. Er läuft dann für eine feste Dauer von `FAN_COOLDOWN_DURATION_MS`, um die warme und feuchte Luft effektiv abzuführen, und schaltet sich danach automatisch ab. Dies verhindert eine zu schnelle Austrocknung durch Dauerbetrieb.

*   **Bewässerungssteuerung (A5):** 
Die Wasserpumpe wird aktiviert, wenn die **Bodenfeuchte (S3)** unter den Zielwert `SOIL_MOISTURE_TARGET` fällt. Die Pumpe läuft dann für eine feste Dauer von `WATERING_DURATION_MS`, um eine definierte Menge Wasser abzugeben.  
**Ausnahme:** Die Pumpe wird niemals aktiviert, wenn der **Wasserstandsensor (S4)** meldet, dass der Wasserbehälter leer ist, um ein Trockenlaufen zu verhindern.

*   **Luftfeuchtesteuerung (A6):** Der Ultraschall-Vernebler (Dunst) wird eingeschaltet, wenn die **relative Luftfeuchtigkeit (S1)** unter den Zielwert `HUMIDITY_TARGET` sinkt. Auch hier sorgt eine Hysterese dafür, dass er sich erst wieder abschaltet, wenn die Luftfeuchtigkeit 5 % über dem Zielwert liegt. 
**Ausnahme:** Der Vernebler wird nur aktiviert, wenn der **Wasserstandsensor (S4)** ausreichend Wasser meldet.

*   **Wasserstands-Überwachung (S4):** Der Füllstandsensor wird kontinuierlich überwacht. Wenn er einen niedrigen Wasserstand (`!WATER_LEVEL_TRIGGERED`) meldet, wird auf dem Display eine bildschirmfüllende, blinkende Warnung angezeigt. Zusätzlich werden Pumpe (A5) und Vernebler (A6) deaktiviert.

*   **Kamerasteuerung (Z3):** In einem festen Intervall (z.B. alle 60 Minuten) wird ein Foto in hoher Auflösung (1600x1200) aufgenommen und auf der SD-Karte (Z2) gespeichert. Der Dateiname enthält einen Zeitstempel, um eine chronologische Sortierung zu ermöglichen (z.B. `img_20241017_143000.jpg`).

### Optimale Klimawerte

Eine Internet-Recherche über optimale Klimawerte für tropische Pflanzen ergab Folgendes:

*   **Temperatur:** 
    - Tropische Pflanzen, die oft aus Regenwäldern stammen, benötigen ein stabiles Klima mit hoher Luftfeuchtigkeit und gleichmäßig hohen Temperaturen. [1]

    - Für tropische Pflanzen sind Tagestemperaturen zwischen 20 °C und 30 °C ideal. [2]

    - Nachts sollten die Temperaturen nicht wesentlich unter 20 °C fallen. [3]

    - Die Bodentemperatur ist für die Wurzelaktivität ebenfalls entscheidend und sollte im warmen Bereich liegen. [2]

*   **Luftfeuchtigkeit:** 
    - Eine hohe relative Luftfeuchtigkeit ist für die meisten tropischen Pflanzen essenziell, um die Transpiration über die Blätter zu minimieren. Werte zwischen 60 % und 80 % sind optimal. [2]

*   **Bodenfeuchte:**  
    - Der Boden sollte konstant feucht, aber niemals durchnässt sein. [4]

    - Staunässe führt schnell zu Wurzelfäule und muss unbedingt vermieden werden. [5]

    - Der Boden sollte zwischen den Gießvorgängen leicht antrocknen können. [5]

*   **Lichtzyklus:** 
    - Ein Lichtzyklus von 12 bis 14 Stunden pro Tag simuliert die Bedingungen am Äquator und fördert ein gesundes vegetatives Wachstum. [6]

Quellen:

* [[1] hoklartherm.de](https://www.hoklartherm.de/ratgeber/tropische-pflanzen-gewaechshaus/)
* [[2] erlebnisgaertnerei.com](https://erlebnisgaertnerei.com/die-richtigen-temperaturen-im-gewaechshaus/)
* [[3] samen.de](https://samen.de/blog/temperaturmanagement-in-der-pflanzenanzucht-fuer-gesundes-pflanzenwachstum.html) 
* [[4] palmenstadl.de](https://palmenstadl.de/Die-richtige-Luftfeuchtigkeit-fuer-mediterrane-tropische-und-Wuestenpflanzen)  
* [[5] urban-jungle.store](https://www.urban-jungle.store/wie-giesse-ich-zimmerpflanzen-richtig/) 
* [[6] harmony-plants.com](https://www.harmony-plants.com/blogs/pflanzenmagazin/topf-und-bodenauswahl-fuer-tropische-pflanzen)

Damit lege ich folgende Sollwerte als Voreinstellung fest (diese können per Webinterface verändert werden): 

*   **`SOIL_TEMPERATUR_TARGET`**: `24.0` °C
*   **`SOIL_MOISTURE_TARGET`**: `50` % (Ein guter Mittelwert, der Staunässe vermeidet)
*   **`AIR_TEMPERATUR_THRESHOLD_HIGH`**: `28.0` °C (Ab hier wird es kritisch, Kühlung ist nötig)
*   **`HUMIDITY_TARGET`**: `70.0` %
*   **`LIGHT_ON_HOUR`**: `6` (6:00 Uhr)
*   **`LIGHT_OFF_HOUR`**: `20` (20:00 Uhr, ergibt einen 14-Stunden-Tag)

### Funktionsumfang

* **Bootvorgang:**
  Nach dem Start wird eine Funktionsprüfung durchgeführt. Die Ergebnisse scrollen durch das Display. Wenn alles funktioniert, wird ein Splash-Screen (mein Portrait) für ein paar Sekunden angezeigt. Danach wird das Dashboard angezeigt. 

* **Dashboard:**
  Das Dashboard teilt den Bildschirm in vier gleichmäßige Bereiche auf. In jedem Bereich wird ein Messwert angezeigt. 

  Die Werte im Dashboard werden mit passenden Icons versehen:

  | Icon (XMB)     |                                                                | Verwendung                                                                       |
  |----------------|----------------------------------------------------------------|----------------------------------------------------------------------------------|
  | thermometer    | thermometer       | Icon für Raumtemperatur (S1)                                                     |
  | wet            | wet                       | Icon für Luftfeuchtigkeit (S1)                                                   |
  | engine_coolant | engine_coolant | Icon für Bodentemperatur (S2)                                                    |
  | moisture       | moisture             | Icon für Bodenfeuchte (S3)                                                       |
  | radiator       | radiator             | Heizung (A3) aktiviert (überlagert Icon für Bodentemperatur)                     |
  | air            | air                       | Lüfter (A4) aktiviert (überlagert Icons für Raumtemperatur und Luftfeuchtigkeit) |
  | rainy_weather  | rainy_weather   | Pumpe (A5) aktiviert (überlagert Icon für Bodenfeuchte)                          |
  | dry            | dry                       | Vernebler (A6) aktiviert (überlagert Icon für Bodenfeuchte)                      |

  Die ursprünglichen Icons habe ich bei [Icons8](https://icons8.com/icons/all--mono--size-small--technique-line) gefunden. 
  Diese unterliegen der [Universal Multimedia License von Icons8](https://intercom.help/icons8-7fb7577e8170/en/articles/5534926-universal-multimedia-license-agreement-for-icons8).
  Demnach dürfen sie verwendet werden, solange das Projekt nicht-kommerziell ist. 
  
  Die Icons habE ich mit GIMP in das XMB-Format konvertiert und im `Include`-Verzeichnis gespeichert, sodass sie auf dem OLED-Display angezeigt werden können.

* **Warnung bei niedrigem Wasserstand:**
  Bevor der Wasserreservoir (Teich) trocken läuft, soll nicht das Dashboard, sondern eine blinkende Warnung auf dem Display angezeigt werden (gern mit Icon). Über das Handy soll der Benutzer auch gewarnt werden (per E-Mail?).

* **Bild aufnehmen:**
  Nach einem festgelegten Intervall (alle x Stunden) wird ein Bild geschossen und auf der SD-Karte gespeichert. Direkt danach wird ein weiteres Bild mit niedrigster Auflösung erzeugt und auf dem Display für ein paar Sekunden angezeigt, um zu zeigen, dass ein Bild gespeichert wurde. 

* **Webinterface:**

Über das Handy kann das Dashboard angezeigt werden. Hier können auch die Sollwerte verändert werden. Außerdem gibt es eine Gallery mit den aufgenommenen Bilder und die Möglichkeit, diese als Zeitraffer-Video abzuspielen. Eine weitere Funktion zeigt Liniendiagramme mit den Messwerten.

## Anhang

### Verwendete ASCII-Schaltzeichen 

<pre>
Datenrichtung (Input, Output, Bidirektional)
◄── 
──► 
◄─►

Buchse
+ O──
- O──
            
IC, Sensor, Aktor
  ┌────────────────┐
──┤ In+       Out+ ├──
  │       U1       │
──┤ In-       Out- ├──
  └────────────────┘

Transistor   │ │ │
  ┌─────┐   ┌┴─┴─┴┐
  │ Q1  │   │C B E│
  │     │   │     │
  │C B E│   │ Q1  │   
  └┬─┬─┬┘   └─────┘
   │ │ │

Kreuzung:
─┼─

Widerstand
───[ R1 ]───

Kondensator
───┤├─── 
   C1

Elko
──⁺▌|───
+  C2  -  (das längere Beinchen ist der Pluspol)

Diode
───▶├───
+  D1  - (Ring)
   
LED
    ↗↗
───▶├───
+  LD1 -  (das längere Beinchen ist der Pluspol)
   
Fotodiode
   ↙↙
───▶├────
+  PD1  -

Lampe
───(╳)───
   HL1

</pre>

### Verwendete Präfixe im Schaltplan

* U: Mikrocontroller, ICs
* K: Relais (Kontaktor)
* S: Sensor
* A: Aktor
* Z: Sonstige Peripherie
* R: Widerstand (Resistor)
* C: Kondensator/Elko (Capacitor)
* P: Stromversorgung (Power Supply)
* Q: Transistor
* D: Diode
* H: Lampe
* J: Anschluss (Stiftleiste, Buchsenleiste, DC-Hohlbuchse,...)

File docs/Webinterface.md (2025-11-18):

## Webinterface

Wir werden ein **asynchrones Webinterface** aufbauen. Das ist entscheidend, damit die Bedienung des Webinterfaces und die Steuerung des Gewächshauses sich nicht gegenseitig blockieren.

Hier ist der Plan für den **Grundaufbau**:

1.  **Bibliotheken installieren:** Wir benötigen die Bibliothek [ESPAsyncWebServer 3.9.0 by ESP32Async](https://github.com/ESP32Async/ESPAsyncWebServer).
2.  **Dateisystem (SPIFFS) einrichten:** Das HTML/CSS/JS für die Webseite legen wir in eine separate Datei, nicht in den C++-Code.
3.  **Eine `WebInterface`-Klasse erstellen:** Diese kapselt die gesamte Server-Logik.
4.  **Der Grundaufbau wird Folgendes können:**
    *   Eine einfache HTML-Seite ausliefern.
    *   Eine WebSocket-Verbindung zum Browser aufbauen.
    *   Die aktuellen Sensordaten **einmal pro Sekunde** vom ESP32 an die Webseite senden.
    *   Die Webseite wird diese Daten empfangen und anzeigen.

### Schritt 1: `platformio.ini` anpassen

Wir müssen die Webserver-Bibliothek hinzufügen und PlatformIO anweisen, das Dateisystem (SPIFFS) für unsere Webseite zu erstellen und hochzuladen.

**Erweitere deine `platformio.ini`-Datei:**

```ini
lib_deps =
    esp32async/ESPAsyncWebServer @ ^3.9.0
    ; esphome/AsyncTCP-esphome @ ^2.1.2

; --- Konfiguration für das SPIFFS-Dateisystem ---
board_build.filesystem = spiffs

```
**Wichtiger Hinweis:** Nach dem Hinzufügen des `extra_scripts` musst du eventuell einmalig VS Code neu starten, damit PlatformIO das Skript erkennt.

---

### Schritt 2: Die Webseite erstellen (`index.html`)

1.  Erstelle im **Hauptverzeichnis** deines Projekts (auf derselben Ebene wie `src`, `lib`, `platformio.ini`) einen neuen Ordner namens `data`.
2.  In diesem `data`-Ordner erstellst du eine Datei namens `index.html`.

**Füge diesen Code in `data/index.html` ein:**

```html
<!DOCTYPE html>
<html lang="de">
<head>
    <meta charset="UTF-8">
    <meta name="viewport" content="width=device-width, initial-scale=1.0">
    <title>Biodom Mini</title>
    <style>
        body { font-family: sans-serif; background-color: #282c34; color: #abb2bf; text-align: center; }
        .container { max-width: 600px; margin: auto; padding: 20px; }
        .sensor { background-color: #3c4049; border-radius: 8px; padding: 15px; margin: 10px; }
        h1, h2 { color: #61afef; }
        .value { font-size: 1.5em; font-weight: bold; color: #98c379; }
    </style>
</head>
<body>
    <div class="container">
        <h1>Biodom Mini - Dashboard</h1>
        
        <div class="sensor">
            <h2>Raumklima</h2>
            <p>Temperatur: <span id="airTemp" class="value">--.-</span> °C</p>
            <p>Luftfeuchte: <span id="humidity" class="value">--</span> %</p>
        </div>
        
        <div class="sensor">
            <h2>Bodenklima</h2>
            <p>Temperatur: <span id="soilTemp" class="value">--.-</span> °C</p>
            <p>Feuchtigkeit: <span id="soilMoisture" class="value">--</span> %</p>
        </div>
    </div>

    <script>
        // Startet eine WebSocket-Verbindung zur IP-Adresse des ESP32
        const gateway = `ws://${window.location.hostname}/ws`;
        let websocket;

        // Diese Funktion wird nach dem Laden der Seite aufgerufen
        window.addEventListener('load', () => {
            initWebSocket();
        });

        function initWebSocket() {
            console.log('Versuche, WebSocket zu öffnen...');
            websocket = new WebSocket(gateway);
            websocket.onopen    = onOpen;
            websocket.onclose   = onClose;
            websocket.onmessage = onMessage;
        }

        function onOpen(event) {
            console.log('Verbindung hergestellt.');
        }

        function onClose(event) {
            console.log('Verbindung getrennt.');
            // Versuche nach 2 Sekunden, die Verbindung erneut herzustellen
            setTimeout(initWebSocket, 2000);
        }

        function onMessage(event) {
            // Empfangene Daten sind ein JSON-String
            console.log(event.data);
            const data = JSON.parse(event.data);
            
            // Aktualisiere die HTML-Elemente mit den neuen Werten
            document.getElementById('airTemp').innerText = data.airTemp.toFixed(1);
            document.getElementById('humidity').innerText = data.humidity.toFixed(0);
            document.getElementById('soilTemp').innerText = data.soilTemp.toFixed(1);
            document.getElementById('soilMoisture').innerText = data.soilMoisture;
        }
    </script>
</body>
</html>
```

---

### Schritt 3: Die `WebInterface`-Bibliothek erstellen

Erstelle den Ordner `lib/WebInterface` mit den Dateien `WebInterface.h` und `WebInterface.cpp`.

#### `WebInterface.h`
```cpp
#pragma once
#include <Arduino.h>
#include <ESPAsyncWebServer.h>

class WebInterface {
public:
    WebInterface(uint16_t port = 80);

    bool begin();

    void broadcastSensorData(float airTemp, float humidity, float soilTemp, int soilMoisture);

private:
    void onWsEvent(AsyncWebSocket *server, AsyncWebSocketClient *client, AwsEventType type, void *arg, uint8_t *data, size_t len);
    
    AsyncWebServer _server;
    AsyncWebSocket _ws;
};
```

#### `WebInterface.cpp`
```cpp
#include "WebInterface.h"
#include <SPIFFS.h>

WebInterface::WebInterface(uint16_t port)
    : _server(port), _ws("/ws") {}

bool WebInterface::begin() {
    if (WiFi.status() != WL_CONNECTED) {
        Serial.println("Web-Fehler: Keine WLAN-Verbindung.");
        return false;
    }

    if (!SPIFFS.begin(true)) {
        Serial.println("Web-Fehler: SPIFFS konnte nicht initialisiert werden.");
        return false;
    }

    // WebSocket-Events an unsere Handler-Funktion binden
    _ws.onEvent([this](AsyncWebSocket *server, AsyncWebSocketClient *client, AwsEventType type, void *arg, uint8_t *data, size_t len) {
        this->onWsEvent(server, client, type, arg, data, len);
    });
    _server.addHandler(&_ws);

    // HTTP-Route für die Hauptseite ("/")
    _server.on("/", HTTP_GET, [](AsyncWebServerRequest *request){
        request->send(SPIFFS, "/index.html", "text/html");
    });

    _server.onNotFound([](AsyncWebServerRequest *request){
        request->send(404, "text/plain", "Seite nicht gefunden");
    });

    _server.begin();
    Serial.println("WebInterface-Dienst bereit.");
    return true;
}

void WebInterface::onWsEvent(AsyncWebSocket *server, AsyncWebSocketClient *client, AwsEventType type, void *arg, uint8_t *data, size_t len) {
    if (type == WS_EVT_CONNECT) {
        Serial.printf("WebSocket-Client #%u verbunden von %s\n", client->id(), client->remoteIP().toString().c_str());
    } else if (type == WS_EVT_DISCONNECT) {
        Serial.printf("WebSocket-Client #%u getrennt\n", client->id());
    } else if (type == WS_EVT_DATA) {
        // Hier werden wir später Befehle vom Browser empfangen
        Serial.println("Daten vom Client empfangen - wird noch nicht verarbeitet.");
    }
}

void WebInterface::broadcastSensorData(float airTemp, float humidity, float soilTemp, int soilMoisture) {
    // Erstelle einen JSON-String mit den Sensordaten.
    // TODO: Später durch die robustere ArduinoJson-Bibliothek ersetzen.
    String json = "{\"airTemp\":" + String(airTemp) +
                  ",\"humidity\":" + String(humidity) +
                  ",\"soilTemp\":" + String(soilTemp) +
                  ",\"soilMoisture\":" + String(soilMoisture) + "}";

    // Sende den JSON-String an alle verbundenen WebSocket-Clients
    _ws.textAll(json);
}
```

---

### Schritt 4: Integration in `main.cpp`

**1. Header und globales Objekt hinzufügen:**
```cpp
// In main.cpp
// ...
#include "NTPClock.h"
#include "WebInterface.h" // <-- NEU

// ...
NTPClock ntpClock;
WebInterface webInterface; // <-- NEUES OBJEKT
```

**2. `setup()` anpassen:**
```cpp
// In der setup()-Funktion von main.cpp
void setup() {
    // ...
    // 5) Netzwerk, Zeit und Webinterface initialisieren
    setupWifi();
    if (!ota.begin()) { /* ... */ }
    if (!ntpClock.begin()) { /* ... */ }
    if (!webInterface.begin()) { // <-- NEU
        halt("WEB FEHLER", "Serverstart fehlgeschlagen");
    }

    // ...
}
```

**3. `loop()` anpassen:**
Wir senden die Daten im selben Takt, in dem das Display aktualisiert wird.
```cpp
// In der loop()-Funktion von main.cpp
void loop() {
    // ...
    if (currentTime - lastDisplayUpdate >= DISPLAY_UPDATE_INTERVAL) {
        lastDisplayUpdate = currentTime;
        handleDisplay();

        // --- NEU: Sende Daten an das Webinterface ---
        // Prüfe, ob die Werte gültig sind, bevor sie gesendet werden.
        if (!isnan(currentAirTemp) && currentSoilMoisture != -1) {
            webInterface.broadcastSensorData(currentAirTemp, currentHumidity, currentSoilTemp, currentSoilMoisture);
        }
    }
    // ...
}
```

---

### Schritt 5: Der Workflow

1.  **Dateisystem hochladen (einmalig):**
    *   Klicke in PlatformIO auf das Alien-Kopf-Icon (PIO) in der linken Leiste.
    *   Wähle unter `ova` -> `Platform` den Task **"Upload Filesystem Image"**.
    *   Dadurch wird die `index.html` auf den ESP32 geladen. Dies musst du nur wiederholen, wenn du die `index.html` änderst.
2.  **Sketch hochladen (per OTA):**
    *   Lade den `main.cpp`-Sketch wie gewohnt hoch.
3.  **Testen:**
    *   Öffne einen Browser auf einem Gerät im selben WLAN.
    *   Gib die IP-Adresse deines ESP32 oder `http://biodom-mini.local` ein.
    *   Die Webseite sollte erscheinen und sich nach einem kurzen Moment mit den Live-Daten füllen.

Das ist der vollständige Grundaufbau. Von hier aus können wir das Interface jetzt schrittweise erweitern, z.B. um Sollwerte vom Browser an den ESP32 zu senden.

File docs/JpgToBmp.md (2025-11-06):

# Sub-Projekt: JpgToBmp

## Anforderung

Ich möchte mit der Kamera (ArduCAM Mini 2MP Plus OV2640) ein Jpg aufnehmen. Der ESP32 DevKitC V2 soll das Bild in ein Byte-Array umwandeln, so dass es auf dem 1.3 Zoll OLED Display SSH1106 angezeigt werden kann.
Das Display hat 128x64 Pixel, ist monochrom, 1 Bit pro Pixel.

### Grundsätzliche Konzeption: Die Daten-Pipeline

Der Kern des Problems ist die Umwandlung (Transformation) von Daten. Wir müssen eine Kette von Verarbeitungsschritten aufbauen, eine sogenannte Pipeline. Diese sieht konzeptionell so aus:

**Quelle (JPG) -> [ Schritt 1 ] -> [ Schritt 2 ] -> [ Schritt 3 ] -> [ Schritt 4 ] -> Ziel (Display)**

1.  **Quelle:** Ein JPG-Datenstrom, der entweder von der `ArduCam`-Klasse oder der `MicroSDCard`-Klasse geliefert wird.
2.  **Schritt 1: JPG-Dekompression:** Die JPG-Daten sind komprimiert. Der erste Schritt muss sein, sie zu dekomprimieren, um an die rohen Pixelinformationen (Farbe für jeden einzelnen Bildpunkt) zu gelangen.
3.  **Schritt 2: Skalierung & Graustufen:** Das dekomprimierte Bild ist riesig (z.B. 1600x1200) und farbig. Wir müssen es auf die Größe des Zieldisplays (z.B. 128x64) herunterskalieren und die Farbinformationen in einen einzigen Graustufenwert pro Pixel umwandeln.
4.  **Schritt 3: Dithering (Monochrom-Umwandlung):** Jetzt haben wir ein kleines Graustufenbild. Da unser Display aber nur "An" (weiß) oder "Aus" (schwarz) kennt, müssen wir entscheiden, welcher Grauwert schwarz und welcher weiß wird. Ein einfacher Schwellenwert würde zu hässlichen, detailarmen Bildern führen. Ein **Dithering-Algorithmus** ist hier die Lösung, um die Illusion von Grautönen zu erzeugen und die Bildqualität drastisch zu verbessern.
5.  **Schritt 4: Bitmap-Formatierung:** Das Ergebnis aus Schritt 3 ist eine 1-Bit-Information (schwarz/weiß) pro Pixel. Diese müssen wir in ein Byte-Array packen, und zwar genau in dem Format, das unsere Display-Bibliothek (`U8g2`) versteht (typischerweise das XBM-Format).
6.  **Ziel:** Der Display-Puffer unserer `OLEDDisplaySH1106`-Klasse, der dann auf dem Bildschirm angezeigt wird.

---

### Wichtige Überlegungen und Stolpersteine (Was ist zu beachten?)

#### 1. JPG-Dekompression (Die größte Hürde)

*   **Wie funktioniert es?** JPG ist ein komplexes, verlustbehaftetes Kompressionsformat. Einen eigenen Decoder zu schreiben, ist ein Projekt für sich. Wir brauchen zwingend eine **externe Bibliothek**.
*   **Welches Werkzeug?** Die mit Abstand beste und etablierteste Bibliothek für Mikrocontroller ist **`TJpgDec` (Tiny JPEG Decompressor)**. Sie ist für genau diesen Zweck geschrieben: ressourcenschonend auf Systemen mit wenig RAM zu laufen.
*   **Was ist zu beachten?** Wir müssen diese Bibliothek in unser PlatformIO-Projekt einbinden.

#### 2. Arbeitsspeicher (RAM) - Die wichtigste Ressource

*   **Das Problem:** Ein dekomprimiertes Farbbild, selbst wenn es klein ist, sprengt schnell den RAM eines ESP32. Ein Bild mit 320x240 Pixeln in Farbe (RGB, 3 Bytes/Pixel) belegt bereits `320 * 240 * 3 = 230.400 Bytes` (~225 KB). Das ist fast die Hälfte des verfügbaren RAMs und lässt kaum Platz für den Rest des Programms. Ein 1600x1200 Bild ist völlig unmöglich.
*   **Die Lösung:** Die `TJpgDec`-Bibliothek ist genial konzipiert. Sie lädt **nie das ganze Bild in den RAM**. Stattdessen arbeitet sie in kleinen Blöcken (sog. MCUs, oft 8x8 oder 16x16 Pixel). Sie dekomprimiert einen Block, ruft dann eine von uns definierte **Callback-Funktion** auf und übergibt uns nur die Pixeldaten dieses kleinen Blocks. In dieser Callback-Funktion führen wir dann unsere Schritte 2-4 (Skalierung, Dithering, Formatierung) durch, bevor der Decoder den nächsten Block liest.
*   **Was ist zu beachten?** Unser gesamter Konvertierungsprozess muss innerhalb dieser Callback-Funktion stattfinden, um den RAM-Verbrauch minimal zu halten.

#### 3. Prozessorlast (CPU) - Die Frage der Geschwindigkeit

*   **Das Problem:** JPG-Dekompression und Dithering sind rechenintensiv. Der ESP32 ist zwar schnell, aber man sollte keine Wunder erwarten.

*   **Die Lösung:** Wir müssen die Erwartungen richtig setzen. Das wird **kein Live-Video-Stream** auf dem OLED sein. Die Konvertierung eines hochauflösenden Fotos wird einige Sekunden dauern. Für die Anzeige von Standbildern ist das aber völlig akzeptabel.

*   **Optimierung:** `TJpgDec` hat eine fantastische Funktion: Es kann das Bild schon **während des Dekomprimierens herunterskalieren** (um den Faktor 2, 4 oder 8). Wenn wir ein 640x480 Bild auf ca. 128x96 (Faktor 5) bringen wollen, können wir es direkt auf 1/4 der Größe (160x120) dekomprimieren lassen. Das spart 93% der Rechenzeit und des Speichers! Das ist der wichtigste Performance-Trick.

#### 4. Dithering (Der Qualitäts-Booster)

*   **Das Problem:** Wenn wir einen Grauwert von 100 (auf einer Skala von 0-255) haben, ist er schwarz oder weiß? Wenn wir einfach sagen "alles unter 128 ist schwarz, alles darüber weiß", verlieren wir alle Details in dunklen und hellen Bereichen. Das Bild sieht aus wie ein Scherenschnitt.

*   **Die Lösung:** Ein Dithering-Algorithmus wie **Floyd-Steinberg**. Er macht Folgendes:
    1.  Er nimmt den Grauwert des aktuellen Pixels (z.B. 100).
    2.  Er entscheidet: "Das ist näher an schwarz (0) als an weiß (255)". Er setzt das Pixel also auf schwarz.
    3.  Er berechnet den "Fehler", den er gemacht hat: `100 - 0 = 100`.
    4.  Diesen Fehler verteilt er anteilig auf die benachbarten Pixel, die noch nicht verarbeitet wurden. Das nächste Pixel, das vielleicht einen Grauwert von 150 hatte, wird dadurch auf z.B. 180 angehoben und hat eine höhere Chance, weiß zu werden.

*   **Ergebnis:** Es entsteht eine Punktwolke, die für das menschliche Auge die Illusion von Grautönen erzeugt. Die Bildqualität ist um Welten besser.

*   **Was ist zu beachten?** Wir müssen eine Implementierung des Floyd-Steinberg-Algorithmus in unsere Callback-Funktion integrieren.

### Schritte zur Umsetzung (Proof Of Concept)

1.  **PoC Schritt 1 (Eigenes JPG als Byte-Array anzeigen):**
Wir stellen den Code zusammen, um ein Bitmap auf dem Display anzeigen zu können. Wir nehmen dann ein JPG-Bild und konvertieren es mit eine einem Online-Tool zum Bitmap (XBM-Format). 

=> Als Bild hab ich mein Portrait gewählt, es mit GIMP auf 128x64 Pixel verkleinert und als JPG gespeichert:

JPG-Bild

Das JPG-Bild hab ich dann dem Tool [Online Image Converter to XBM](https://www.online-utility.org/image/convert/to/XBM) konvertiert:

XBM-Bild

2.  **PoC Schritt 2 (Eigene Konverter-Funktion):**
Hier implementieren wir die Kernlogik (TJpgDec, Skalierung, Dithering) und vergleichen das Ergebnis mit dem aus Schritt 1.

3.  **PoC Schritt 4 (Stream-Verarbeitung):**
Hier abstrahieren wir die Funktion, sodass sie nicht mehr von einer festen Datei abhängt, sondern jeden beliebigen Datenstrom verarbeiten kann.

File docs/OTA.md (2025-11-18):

# OTA (Over-The-Air)

OTA ermöglicht das Hochladen des Codes über WLAN.

## 📦 Installation & Konfiguration

Für ein OTA-Update müssen folgende Angaben in die `platformio.ini` eingetragen werden:

```ini
[platformio]
extra_configs = secrets.ini

[env:esp32-ova]
; ...
upload_protocol = espota
upload_port = biodom-mini-dev
upload_flags = --auth=${common.ota_password}

```
* `espota` steht für "ESP OTA"-Protokoll.
* Der `upload_port` ist der Hostname oder die IP-Adresse.
* In `upload_flags` ist das Passwort angegeben - hier indirekt über die separate Ini-Datei `secrets.ini`:
  ```ini
  [common]
  ota_password = 4321
  ```
  **WICHTIG:** `secrets.ini` sollte per `.gitignore` vom Git-Repository ausgeschlossen werden!

**Anmerkung:**

Mit der Arduino IDE kann der Code auch drahtlos hochgeladen werden.
Wenn das Programm läuft, ist der Port des Entwicklungsboards keine COM-Schnittstelle mehr, sondern ein Netzwerk-Anschluss (Menüpunkt Tools/Port, u.U. erst nach Neustart sichtbar):

Tools > Port

## 💻 Beispiel-Code

s. [sketches/OTA_Test](/sketches/OTA_Test/OTA_Test.ino)

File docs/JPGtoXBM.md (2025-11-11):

# Teilprojekt: JPGtoXBM

## Anforderung

Ich möchte mit der Kamera (ArduCAM Mini 2MP Plus OV2640) ein Jpg aufnehmen. Der ESP32 DevKitC V2 soll das Bild in ein Byte-Array umwandeln, so dass es auf dem 1.3 Zoll OLED Display SSH1106 angezeigt werden kann.
Das Display hat 128x64 Pixel, ist monochrom, 1 Bit pro Pixel.

### Grundsätzliche Konzeption: Die Daten-Pipeline

Die Herausforderung ist Transformation der Bilddaten. Diese ist rechenintensiv. Der ESP32 ist zwar schnell, aber man sollte keine Wunder erwarten. Die Konvertierung eines hochauflösenden Fotos wird einige Sekunden dauern. Für die Anzeige von Standbildern ist das aber völlig akzeptabel. 

Wir müssen eine Kette von Verarbeitungsschritten aufbauen, eine sogenannte Pipeline. Diese sieht konzeptionell so aus:

**JPG-Stream -> [ JPG-Dekompression ] -> [ Skalierung & Graustufen ] -> [ Dithering ] -> [ XBM-Formatierung ] -> XBM-Stream**

Die ArduCam oder die SD-Karte liefert den JPG-Datenstrom an die Pipeline.

1.  **Verarbeitungsschritt 1: JPG-Dekompression:**  
Die JPG-Daten sind komprimiert. Der erste Schritt muss sein, sie zu dekomprimieren, um an die rohen Pixelinformationen (Farbe für jeden einzelnen Bildpunkt) zu gelangen.
Das erledigt die Bibliothek [TJpg_Decoder by Bodmer](https://github.com/Bodmer/TJpg_Decoder).

(TODO: nicht diese: [JPEGDEC by Larry Bank](https://github.com/bitbank2/JPEGDEC))

Sie ist für genau diesen Zweck für zur Ausführung auf Mikrocontroller geschrieben. Um den verfügbaren RAM zu schonen, arbeitet die Bibliothek in kleinen Blöcken (sog. MCUs, oft 8x8 oder 16x16 Pixel). Sie dekomprimiert einen Block, und übergibt diesen an eine **Callback-Funktion**. In dieser Callback-Funktion führen wir dann unsere nachfolgenden Schritte (Skalierung, Dithering, Formatierung) durch, bevor der Decoder den nächsten Block liest.

2.  **Verarbeitungsschritt 2: Skalierung & Graustufen:**  
Das dekomprimierte Bild ist für das Display zu groß und farbig. Wir müssen es auf die Größe des Zieldisplays (128 x 64) herunterskalieren und die Farbinformationen in einen Graustufenwertumwandeln. 

3.  **Verarbeitungsschritt 3: Dithering (Monochrom-Umwandlung):**  
Jetzt haben wir ein kleines Graustufenbild. Da unser Display aber nur "An" (weiß) oder "Aus" (schwarz) kennt, müssen wir entscheiden, welcher Grauwert Schwarz und welcher weiß wird. Ein einfacher Schwellenwert würde zu hässlichen, detailarmen Bildern führen. Der **Dithering-Algorithmus von Floyd-Steinberg** ist hier die Lösung. Er macht folgendes:

    1.  Er nimmt den Grauwert des aktuellen Pixels (z.B. 100).
    2.  Er entscheidet: "Das ist näher an schwarz (0) als an weiß (255)". Er setzt das Pixel also auf Schwarz.
    3.  Er berechnet den "Fehler", den er gemacht hat: `100 - 0 = 100`.
    4.  Diesen Fehler verteilt er anteilig auf die benachbarten Pixel, die noch nicht verarbeitet wurden. Das nächste Pixel, das vielleicht einen Grauwert von 150 hatte, wird dadurch auf z.B. 180 angehoben und hat eine höhere Chance, weiß zu werden.  
    
    Ergebnis: Es entsteht eine Punktwolke, die für das menschliche Auge die Illusion von Grautönen erzeugt. Die Bildqualität ist um Welten besser.

4.  **Verarbeitungsschritt 4: XBM-Formatierung:**  
Das Ergebnis aus Schritt 3 muss nun in das XBM-Format (X BitMap) überführt werden (welches die U8g2-Bibliothek versteht). Das XBM hat diese Eigenschaften:
    - Monochrom: Es speichert nur 1-Bit-Informationen (schwarz/weiß).
    - C-Quellcode: Es ist kein binäres Dateiformat, sondern wird direkt als `C`-Quellcode gespeichert (`static const unsigned char ...`).
    - Feste Struktur: Jedes Byte repräsentiert 8 horizontale Pixel. Die Bits werden "rückwärts" gelesen, d.h. das niedrigstwertige Bit (LSB) ist das linkeste Pixel.

Das Ende der Pipeline ist ein XBM-Datenstrom, der von der `OLEDDisplaySH1106`-Klasse entgegengenommen und als Bild auf auf dem Bildschirm angezeigt werden kann.

### Proof Of Concept

Die Sketche hierzu sind unter `sketches/JPGtoXBM` abgelegt.

1.  **Proof Of Concept 1:** Wie wird ein im XBM-Format umgewandeltes JPG-Bild auf dem Display angezeigt? Ist die Qualität ausreichend? 
    *  Als Bild habe ich mein Portrait gewählt, es mit GIMP auf 128x64 Pixel verkleinert und im JPG-Format gespeichert:  
    JPG-Bild  
    Das JPG-Bild habe ich dann mit dem Online-Tool [Convert Image to XBM](https://www.online-utility.org/image/convert/to/XBM) konvertiert:  
    XBM-Bild  
    Die resultierenden XBM-Daten habe ich als Headerdatei unter `frank_128x64_xbm.h` abgelegt. Einmal im `Include`-Verzeichnis (da ich sie auch als Splash-Screen verwenden möchte) und einmal in Ordner, in dem auch der Sketch liegt (damit die Arduino IDE diese einbinden kann).
    *  Um das XBM-Bild anzuzeigen, habe ich den Demo-Sketch `OLED_Display_SSH1106_Test.ino` genommen und alles bis auf das absolut Notwendigste entfernt. 

2.  **Proof Of Concept 2:** Wie kann auf dem ESP32 ein JPG-Bild in ein XBM-Bild umgewandelt werden? Reicht der RAM und wie lange dauert die  Verarbeitungszeit?  

    * In der Arduino IDE habe ich mittels Library Manager `https://github.com/bitbank2/JPEGDecoder` installiert.
    (TODO: nicht diese: `JPEGDEC 1.8.4 by Larry Bank`)
    * Das JPG-Bild aus PoC 1 (./assets/frank_128x64.jpg) habe ich nach folgender Anleitung von Meta-Angaben befreit:  
        1.  Öffne das Bild in GIMP.
        2.  Gehe zu `Datei -> Exportieren als...`.
        3.  Wähle als Dateityp `JPEG-Bild (*.jpg)` und gib ihm einen neuen Namen, z.B. `frank_clean_128x64.jpg` (im selben Ordner in dem auch der Sketch liegt).
        4.  Klicke auf `Exportieren`. Es öffnet sich ein Dialogfenster "Bild als JPEG exportieren".
        5.  Klappe den Bereich `Erweiterte Optionen` auf.
        6.  Entfernte die Haken bei folgenden Optionen:
            *   `EXIF-Daten speichern`
            *   `XMP-Daten speichern`
            *   `IPTC-Daten speichern`
            *   `Vorschaubild speichern`
            *   `Progressiv`
        7.  Klicke auf `Exportieren`.
    * Die Bytes des bereinigten JPG-Bildes habe ich dann in einem C-Array als Headerdatei `image_jpg.h` gespeichert (im selben Ordner wie der Sketch). Das hat das Python-Skript `convert.py` (auch im selben Ordner wie der Sketch) für mich erledigt. Statt dessen kann man auch das Online-Tool [File to hexadecimal converter](http://tomeko.net/online_tools/file_to_hex.php) nutzen - das Ergebnis ist das gleiche.

    🚧🚧🚧 TODO: Ab hier ist der PoC noch nicht umgesetzt! 🚧🚧🚧   
    Der Sketch baut auf dem Sketch von PoC 1 auf. Es lädt aber nicht die XBM-Daten, sondern die JPG-Daten, führt die Konvertierung durch und zeigt schließlich die resultierenden XBM-Daten wie im PoC 1 auf dem Display an.

3.  **Proof Of Concept 3:** Wie können die JPG-Daten von der Kamera bzw. von der SD-Karte als Datenstrom entgegengenommen werden? WIe kann der Datenstrom direkt an das Display weitergeleitet werden?

    Hier abstrahieren wir die Funktion, sodass sie nicht mehr von einer festen Datei abhängt, sondern jeden beliebigen Datenstrom verarbeiten kann.

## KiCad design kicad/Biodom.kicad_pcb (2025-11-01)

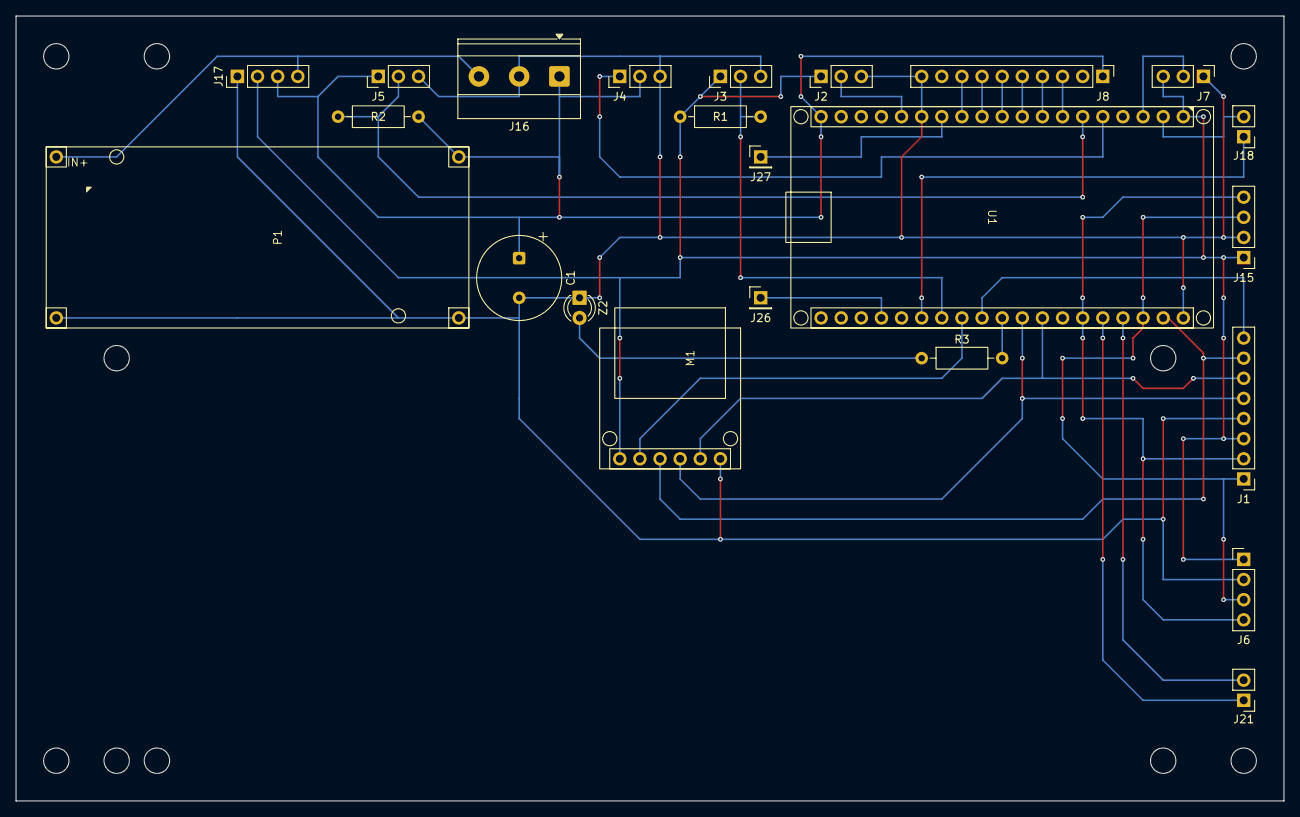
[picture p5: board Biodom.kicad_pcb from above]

Board: 2 copper layers, 160.0 x 99.1 mm, 23 parts (0 on the bottom side), 30 nets.

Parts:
C1: 470µF; CP_Radial_Tantal_D10.5mm_P5.00mm
J1: Kamera; PinHeader_1x08_P2.54mm_Vertical
J2: Luft; PinHeader_1x03_P2.54mm_Vertical
J3: Bodentemperatur; PinHeader_1x03_P2.54mm_Vertical
J4: Bodenfeuchte; PinHeader_1x03_P2.54mm_Vertical
J5: Wasserstand; PinHeader_1x03_P2.54mm_Vertical
J6: Lichtstärke; PinHeader_1x04_P2.54mm_Vertical
J7: Reserve; PinHeader_1x03_P2.54mm_Vertical
J8: Relais; PinHeader_1x10_P2.54mm_Vertical
J15: Display; PinHeader_1x04_P2.54mm_Vertical
J16: DC; TerminalBlock_Phoenix_MKDS-1,5-3-5.08_1x03_P5.08mm_Horizont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
J17: PWR; PinHeader_1x04_P2.54mm_Vertical
J18: RST; PinHeader_1x02_P2.54mm_Vertical
J21: UART; PinHeader_1x02_P2.54mm_Vertical
J26: TDO; PinHeader_1x01_P2.54mm_Vertical
J27: TDI; PinHeader_1x01_P2.54mm_Vertical
M1: SD-Karte; MicroSD_SPI_Modul_Socket
P1: Spannungsteiler; XL4015_Module_Socket
R1: 4,7kΩ; R_Axial_DIN0207_L6.3mm_D2.5mm_P10.16mm_Horizontal
R2: 10kΩ; R_Axial_DIN0207_L6.3mm_D2.5mm_P10.16mm_Horizontal
R3: 330Ω; R_Axial_DIN0207_L6.3mm_D2.5mm_P10.16mm_Horizontal
U1: ESP32; ESP32_DevKitC_V2_Socket
Z2: LED; LED_D3.0mm

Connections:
+3V3: J1.3, J2.1, J3.1, J6.1, J7.3, J15.1, J17.2, M1.1 (3.3V), R1.1, U1.1 (3V3)
+5V: C1.1, J4.2, J5.1, J8.1, J16.1, J17.3, P1.3 (OUT+), R2.1, U1.19 (5V)
+12V: J16.3, J17.4, P1.1 (IN+)
/EN: J18.2, U1.2 (EN)
/G0: J18.1, U1.25 (G0)
/G1: J21.2, U1.35 (TXD)
/G3: J21.1, U1.34 (RXD)
/G4: J3.2, R1.2, U1.26 (G4)
/G5: R3.2, U1.29 (G5)
/G12: J27.1, U1.13 (G12)
/G13: J2.2, U1.15 (G13)
/G14: J8.8, U1.12 (G14)
/G15: J26.1, U1.23 (G15)
/G16: M1.2 (CS), U1.27 (G16)
/G17: J1.8, U1.28 (G17)
/G18: J1.5, M1.4 (CLK), U1.30 (G18)
/G19: J1.6, M1.5 (MISO), U1.31 (G19)
/G21: J1.2, J6.4, J15.4, U1.33 (G21)
/G22: J1.1, J6.3, J15.3, U1.36 (G22)
/G23: J1.7, M1.3 (MOSI), U1.37 (G23)
/G25: J8.5, U1.9 (G25)
/G26: J8.6, U1.10 (G26)
/G27: J8.7, U1.11 (G27)
/G32: J8.3, U1.7 (G32)
/G33: J8.4, U1.8 (G33)
/G34: J4.1, U1.5 (G34)
/G35: J5.2, R2.2, U1.6 (G35)
/G36: J7.2, U1.3 (SP)
/LED+: R3.1, Z2.2 (A)
GND: C1.2, J1.4, J2.3, J3.3, J4.3, J5.3, J6.2, J7.1, J8.10, J15.2, J16.2, J17.1, M1.6 (GND), P1.2 (IN-), P1.4 (OUT-), U1.14 (GND), U1.38 (GND), Z2.1 (K)

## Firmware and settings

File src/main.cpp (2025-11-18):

/**
 * @file main.cpp
 * @brief Hauptprogramm für das "Biodom Mini" Projekt.
 * 
 * Diese Datei enthält die Hauptlogik zur Steuerung des Gewächshauses.
 * Sie initialisiert alle Sensoren und Aktoren, liest periodisch Messwerte aus,
 * wendet die Steuerungslogik an und aktualisiert die Anzeige.
 * 
 * @version 1.0.3
 * @date 13.11.2025
 * @author Frank Rohlfing
 */

#include <Arduino.h>
#include <SD.h>
#include <Wire.h>
#include <WiFi.h>
#include <ArduinoOTA.h>

// -- Einbinden der Konfiguration und der lokalen Bibliotheken --
#include "config.h"
#include "secrets.h"
#include "ArduCamMini2MPPlusOV2640.h"
#include "LED.h"
#include "MicroSDCard.h"
#include "OLEDDisplaySH1106.h"
#include "Relay.h"
#include "SensorAM2302.h"
#include "SensorBH1750.h"
#include "SensorCapacitiveSoil.h"
#include "SensorDS18B20.h"
#include "SensorXKCY25NPN.h"

// Splash Screen
#include "xbm/frank_128x64_xbm.h" // definiert das C-Array frank_128x64_bits[]

// Icons für das Dashboard
#include "xbm/thermometer_16x16_xbm.h"    // Icon für Raumtemperatur (S1)
#include "xbm/wet_16x16_xbm.h"            // Icon für Luftfeuchtigkeit (S1)
#include "xbm/engine_coolant_16x16_xbm.h" // Icon für Bodentemperatur (S2)
#include "xbm/moisture_16x16_xbm.h"       // Icon für Bodenfeuchte (S3)

// Icons, wenn Aktoren aktiv sind
#include "xbm/radiator_16x16_xbm.h"      // Heizung (A3) aktiviert (überlagert Icon für Bodentemperatur)
#include "xbm/air_16x16_xbm.h"           // Lüfter (A4) aktiviert (überlagert Icons für Raumtemperatur und Luftfeuchtigkeit)
#include "xbm/rainy_weather_16x16_xbm.h" // Pumpe (A5) aktiviert (überlagert Icon für Bodenfeuchte)
#include "xbm/dry_16x16_xbm.h"           // Vernebler (A6) aktiviert (überlagert Icon für Luftfeuchtigkeit)

// === Globale Objektinstanzen ===
// Hier werden für alle Hardware-Komponenten Objekte erstellt.
// Die Pin-Konfiguration wird aus der config.h geladen.

// --- Sensoren ---
SensorAM2302 airSensor(PIN_AIR_SENSOR); // Raumtemperatur- und Luftfeuchtigkeitssensormodul AM2302 (S1)
SensorDS18B20 soilTempSensor(PIN_SOIL_TEMPERATUR_SENSOR); // Bodentemperatursensor DS18B20 (S2)
SensorCapacitiveSoil soilMoistureSensor(PIN_SOIL_MOISTURE_SENSOR, SOIL_MOISTURE_ADC_DRY, SOIL_MOISTURE_ADC_WET); // Kapazitiver Bodenfeuchtigkeitssensor v1.2 (S3)
SensorXKCY25NPN waterLevelSensor(PIN_WATER_LEVEL_SENSOR); // Berührungsloser Füllstandsensor XKC-Y25-NPN (S4)
SensorBH1750 lightSensor; // Lichtsensor GY-302 BH1750 (S5)

// --- Aktoren (Relais) ---
// Die Relais sind active-low, d.h. LOW schaltet sie ein.
Relay lamp1Relay(PIN_LAMP1_RELAY);    // Lampe 1 (A1)
Relay lamp2Relay(PIN_LAMP2_RELAY);    // Lampe 2 (A2)
Relay heaterRelay(PIN_HEATER_RELAY);  // Heizer (A3)
Relay fanRelay(PIN_FAN_RELAY);        // Lüfter (A4)
Relay pumpRelay(PIN_PUMP_RELAY);      // Wasserpumpe (A5)
Relay misterRelay(PIN_MISTER_RELAY);  // Vernebler (A6)

// --- Sonstige Peripherie ---
OLEDDisplaySH1106 display;            // 1.3 Zoll OLED Display, SSH1106 (Z1)
MicroSDCard sdCard(PIN_SPI_SD_CS);    // MicroSD SPI Kartenleser (Z2)
ArduCamMini2MPPlusOV2640 camera(PIN_SPI_CAMERA_CS); // ArduCAM Mini 2MP Plus, OV2640 (Z3)
LED debugLed(PIN_DEBUG_LED);          // LED (Z4)

// === Globale Variablen zur Zustandsspeicherung ===

// --- Sensorwerte ---
// Diese Variablen speichern die zuletzt gemessenen Werte, um sie im Programmablauf zu verwenden.
// Sie werden mit "Not a Number" (NAN) oder -1 initialisiert, um anzuzeigen, dass noch keine gültige Messung stattgefunden hat.
float currentAirTemp = NAN;         // Aktuelle Raumtemperatur in °C (S1)
float currentHumidity = NAN;        // Aktuelle Luftfeuchtigkeit in % (S1)
float currentSoilTemp = NAN;        // Aktuelle Bodentemperatur in °C (S2)
int currentSoilMoisture = -1;       // Aktuelle Bodenfeuchte in % (S3), -1 bedeutet "ungültig/nicht gemessen"
bool isWaterLevelOk = false;        // Zustand des Wasserfüllstands (S4), startet mit 'false' (kein Wasser), bis erste Messung erfolgt.
float currentLightLux = NAN;        // Aktuelle Lichtstärke in Lux (S5)

// --- Zeitsteuerung für nicht-blockierende Operationen ---
// Diese Variablen speichern den Zeitpunkt (in Millisekunden seit Start) der letzten Ausführung,
// um Aktionen in festen Intervallen ohne blockierende delay()-Aufrufe durchzuführen.
unsigned long lastSensorRead = 0;     // Zeitpunkt der letzten Sensormessung
unsigned long lastDisplayUpdate = 0;  // Zeitpunkt der letzten Display-Aktualisierung
unsigned long lastCameraCapture = 0;  // Zeitpunkt der letzten Kameraaufnahme

// === Funktionsprototypen ===
void handleSensors();
void handleControlLogic();
void handleDisplay();
void handleCamera();

/**
 * Hält das Programm an.
 * 
 * Gibt vor dem Halt eine Meldung und optional weitere Details aus.
 * Zusätzlich wird die Debug-LED eingeschaltet.
 * @param message Die Fehlermeldung, die auf dem Display und seriell ausgegeben wird.
 * @param detail Details zur Fehlermeldung (optional).
 */
void halt(const char* message, const char* detail = "") {
    Serial.println(message);
    display.addLogLine(message);
    if (strlen(detail) > 0) {
        Serial.println(detail);
        display.addLogLine(detail);
    }
    Serial.println(F("System angehalten"));
    display.addLogLine(F("System angehalten"));

    // LED dauerhaft einschalten, um den Halt zu signalisieren.
    debugLed.on(); 

    // Endlosschleife, um das Programm anzuhalten
    while (true) {
        delay(100); // Prozessor entlasten
    }
}

/**
 * Gibt den Logeintrag aus.
 * 
 * Es wird etwas gewartet, damit der Eintrag auch auf dem Display gelesen werden kann, 
 * bevor eventuell der nächste Eintrag angezeigt wird.
 */
void log(const char* message) {
    Serial.println(message);
    display.addLogLine(message);
    delay(1000);
}

/**
 * @brief Initialisierungsroutine, wird einmal beim Start ausgeführt.
 */
void setup() {
    // Zufallsgenerator mit einem unvorhersehbaren Wert von einem offenen Analog-Pin initialisieren 
    randomSeed(analogRead(36)); // der GPIO36 ist ungenutzt

    // --- Debug-LED, serielle Schnittstelle und Display initialisieren ---
    // (als erstes, damit Fehler so früh wie möglich angezeigt werden können)

    // 1) Debug-LED (Z4) initialisieren
    // Die LED ist standardmäßig aus. 
    // Sie signalisiert, dass da System nicht gestartet werden konnte.
    debugLed.begin(); 

    // 2) Serielle Schnittstelle initialisieren
    Serial.begin(115200);
    //while (!Serial); // Auf serielle Verbindung warten
    Serial.println("Biodom Mini startet");

    // 3) I2C-Bus initialisieren
    // Für den ESP32 ist es eine gute Praxis, die SDA- und SCL-Pins explizit anzugeben.
    Wire.begin(PIN_I2C_SDA, PIN_I2C_SCL);

    // 4) Display (Z1) initialisieren
    if (!display.begin()) {  
        Serial.println("Kein Display! System angehalten.");
        // halt() sollte hier besser noch nicht aufgerufen werden, da die Funktion das Display voraussetzt
        debugLed.on(); 
        while (true) { delay(100); } // Endlosschleife, um das Programm anzuhalten
    }

    // --- Netzwerkdienste starten ---

    // 5) Netzwerk initialisieren
    log("Verbinde mit WLAN...");
    WiFiClass::mode(WIFI_STA); // Station Mode (Client)
    WiFiClass::setHostname(HOSTNAME);
    WiFi.begin(WIFI_SSID, WIFI_PASSWORD);
    int attempts = 0;
    while (WiFiClass::status() != WL_CONNECTED && attempts < 20) { // max. 20 * 500ms = 10 Sekunden lang versuchen
        delay(500);
        Serial.print(".");
        attempts++;
    }
    Serial.println();
    if (WiFiClass::status() != WL_CONNECTED) {
        halt("WLAN FEHLER", "Verbindung fehlgeschlagen");
    }
    log("WLAN verbunden!");
    String ipMessage = "IP: " + WiFi.localIP().toString();
    log(ipMessage.c_str());
    String hostMessage = "Host: " + String(WiFiClass::getHostname());
    log(hostMessage.c_str());

    // 6) OTA-Dienst starten
    ArduinoOTA.setHostname(HOSTNAME);
    ArduinoOTA.setPassword(OTA_PASSWORD);
    ArduinoOTA.begin();
    log("OTA-Dienst bereit");

    // 7. NTP-Client initialisieren
    configTime(GMT_OFFSET, DAYLIGHT_OFFSET, NTP_SERVER); // started Hintergrund-Task für Zeitsynchronisation 
    log("Synchronisiere Zeit...");
    attempts = 0;
    tm timeInfo{};
    while (!getLocalTime(&timeInfo) && attempts < 20) { // max. 20 * 500ms = 10 Sekunden lang versuchen
        delay(500);
        Serial.print(".");
        attempts++;
    }
    Serial.println();
    if (!getLocalTime(&timeInfo)) {
        halt("NTP FEHLER", "Zeit nicht ermittelt");
    }
    char timeString[20];
    strftime(timeString, sizeof(timeString), "%d.%m.%Y %H:%M:%S", &timeInfo);
    log(timeString);

    // --- Restliche Hardware-Komponenten initialisieren ---

    log("Systemstart...");

    // S1
    if (!airSensor.begin()) { 
        halt("Luftsensor FEHLER", airSensor.getErrorMessage());
    } 
    log("Luftsensor OK");

    // S2
    if (!soilTempSensor.begin()) { 
        halt("Bodentemp. FEHLER"); 
    } 
    log("Bodentemperatur OK"); 

    // S3  
    if (!soilMoistureSensor.begin()) { 
        halt("Bodenfeuchte FEHLER"); 
    } 
    log("Bodenfeuchtesensor OK"); 

    // S4
    if (!waterLevelSensor.begin()) {
        halt("Wasserstand FEHLER"); 
    } 
    log("Wasserstandsensor OK");

    // S5 (I2C-Gerät)
    if (!lightSensor.begin()) { 
        halt("Lichtsensor FEHLER"); 
    } 
    log("Lichtsensor OK"); 

    // Sonstige Peripheriegeräte

    // Z2
    if (!sdCard.begin()) { 
        halt("SD-Karte FEHLER"); 
    } 
    log("SD-Karte OK"); 

    // Z3 (I2C-Gerät)
    if (!camera.begin()) { 
        halt("Kamera FEHLER"); 
    } 
    log("Kamera OK"); 

    // Relais initialisieren
    lamp1Relay.begin();  // A1
    lamp2Relay.begin();  // A2
    heaterRelay.begin(); // A3
    fanRelay.begin();    // A4
    pumpRelay.begin();   // A5
    misterRelay.begin(); // A6
    log("Aktoren initialisiert");

    // --- Initialisierung erfolgreich ---

    Serial.println("System gestartet.");

    // Splash-Screen kurz anzeigen (signalisiert, dass alles ok ist)
    display.showFullscreenXBM(128, 64, frank_128x64_xbm);
    delay(1000);

    // Initiales Auslesen aller Sensoren
    handleSensors();
}

/**
 * @brief Hauptschleife, wird kontinuierlich ausgeführt.
 */
void loop() {
    ArduinoOTA.handle();

    unsigned long currentTime = millis();

    // Nicht-blockierende Handler aufrufen
    if (currentTime - lastSensorRead >= SENSOR_READ_INTERVAL) {
        lastSensorRead = currentTime;
        handleSensors();
    }

    if (currentTime - lastDisplayUpdate >= DISPLAY_UPDATE_INTERVAL) {
        lastDisplayUpdate = currentTime;
        handleDisplay();
    }

    if (currentTime - lastCameraCapture >= CAMERA_CAPTURE_INTERVAL) {
        lastCameraCapture = currentTime;
        handleCamera();
    }

    // Steuerungslogik in jedem Zyklus ausführen, um schnell reagieren zu können
    handleControlLogic();

    // Update-Funktionen für zeitgesteuerte Komponenten aufrufen
    debugLed.update();
    fanRelay.update();
    pumpRelay.update();
    display.update();
}

/**
 * @brief Liest alle Sensoren aus und speichert die Werte in globalen Variablen.
 */
void handleSensors() {
    debugLed.on(); // LED an während des Lesens

    if (airSensor.read()) {
        currentAirTemp = airSensor.getTemperature();
        currentHumidity = airSensor.getHumidity();
    }
    
    if (soilTempSensor.read()) { 
        currentSoilTemp = soilTempSensor.getTemperature(); 
    }
    
    if (soilMoistureSensor.read()) { 
        currentSoilMoisture = soilMoistureSensor.getPercent(); 
    }
    
    if (lightSensor.read()) { 
        currentLightLux = lightSensor.getLux(); 
    }
    
    if (waterLevelSensor.read()) { 
        isWaterLevelOk = waterLevelSensor.isWaterDetected(); 
    }

    debugLed.off(); // LED aus nach dem Lesen

    Serial.printf("Luft: %.1f°C, %.1f%% | Boden: %.1f°C, %d%% | Licht: %.0f Lux | Wasser OK: %d\n", 
        currentAirTemp, 
        currentHumidity, 
        currentSoilTemp, 
        currentSoilMoisture, 
        currentLightLux, 
        isWaterLevelOk
    );
}

/**
 * @brief Aktualisiert das OLED-Display mit den aktuellen Sensorwerten.
 */
void handleDisplay() {
    // Wenn der Wasserstand niedrig ist, hat die Warnung absolute Priorität.
    if (!isWaterLevelOk) {
        display.showFullscreenAlert("WASSER\nNACHFUELLEN", true);
        return;
    }

    // --- Quadrant Oben Links: Raumtemperatur (S1) ---

    if (fanRelay.isOn()) {
        // Wenn der Lüfter läuft, zeige das Icon für den Lüfter.
        display.setDashboardIcon(OLEDDisplaySH1106::TOP_LEFT, 16, 16, air_16x16_xbm);
    } else {
        // Sonst zeige das Icon für die Raumtemperatur.
        display.setDashboardIcon(OLEDDisplaySH1106::TOP_LEFT, 16, 16, thermometer_16x16_xbm);
    }

    // Messwert anzeigen
    if (!isnan(currentAirTemp)) {
        display.setDashboardText(OLEDDisplaySH1106::TOP_LEFT, String(currentAirTemp, 1) + "C");
    } else {
        display.setDashboardText(OLEDDisplaySH1106::TOP_LEFT, "FEHLER");
    }

    // --- Quadrant Oben Rechts: Luftfeuchtigkeit (S1) ---

    if (misterRelay.isOn()) {
        // Wenn der Vernebler läuft, zeige das Icon für den Vernebler.
        display.setDashboardIcon(OLEDDisplaySH1106::TOP_RIGHT, 16, 16, dry_16x16_xbm);
    } else if (fanRelay.isOn()) {
        // Wenn der Lüfter läuft, zeige das Icon für den Lüfter (da er die Raumtemperatur UND die Luftfeuchtigkeit beeinflusst).
        display.setDashboardIcon(OLEDDisplaySH1106::TOP_RIGHT, 16, 16, air_16x16_xbm);
    } else {
        // Sonst zeige das Icon für die Luftfeuchtigkeit.
        display.setDashboardIcon(OLEDDisplaySH1106::TOP_RIGHT, 16, 16, wet_16x16_xbm);
    }

    // Messwert anzeigen
    if (!isnan(currentHumidity)) {
        display.setDashboardText(OLEDDisplaySH1106::TOP_RIGHT, String(currentHumidity, 0) + "%");
    } else {
        display.setDashboardText(OLEDDisplaySH1106::TOP_RIGHT, "FEHLER");
    }

    // Quadrant Unten Links: Bodentemperatur (S2)

    if (heaterRelay.isOn()) {
        // Wenn die Heizung an ist, zeige das Icon für den Heizer.
        display.setDashboardIcon(OLEDDisplaySH1106::BOTTOM_LEFT, 16, 16, radiator_16x16_xbm);
    } else {
        // Sonst zeige das Icon für die Bodentemperatur.
        display.setDashboardIcon(OLEDDisplaySH1106::BOTTOM_LEFT, 16, 16, engine_coolant_16x16_xbm);
    }
    
    // Messwert anzeigen
    if (!isnan(currentSoilTemp)) {
        display.setDashboardText(OLEDDisplaySH1106::BOTTOM_LEFT, String(currentSoilTemp, 1) + "C");
    } else {
        display.setDashboardText(OLEDDisplaySH1106::BOTTOM_LEFT, "FEHLER");
    }

    // Quadrant Unten Rechts: Bodenfeuchte (S3)
    
    if (pumpRelay.isOn()) {
        // Wenn die Pumpe läuft (Bewässerung aktiv), zeige das Icon für die Pumpe.
        display.setDashboardIcon(OLEDDisplaySH1106::BOTTOM_RIGHT, 16, 16, rainy_weather_16x16_xbm);
    } else {
        // Sonst zeige das Icon für die Bodenfeuchte.
        display.setDashboardIcon(OLEDDisplaySH1106::BOTTOM_RIGHT, 16, 16, moisture_16x16_xbm);
    }

    // Messwert anzeigen
    if (currentSoilMoisture != -1) {
        display.setDashboardText(OLEDDisplaySH1106::BOTTOM_RIGHT, String(currentSoilMoisture) + "%");
    } else {
        display.setDashboardText(OLEDDisplaySH1106::BOTTOM_RIGHT, "FEHLER");
    }

    // Nachdem alle Quadranten konfiguriert sind, das gesamte Dashboard auf dem Display zeichnen.
    display.showDashboard();  
}

/**
 * @brief Implementiert die Steuerungslogik für alle Aktoren.
 */
void handleControlLogic() {
    tm timeInfo{};
    if (!getLocalTime(&timeInfo)) {
        log("Fehler beim Abrufen der Zeit."); // dürfte nie vorkommen, da im Setup die Zeit synchronisiert wurde
        return;
    }
    int currentHour = timeInfo.tm_hour;

    // -- Steuerung für die Lampen (A1 und A2) --
    
    if (currentHour >= LIGHT_ON_HOUR && currentHour < LIGHT_OFF_HOUR) { // "Licht an"-Zeitfenster ist gegeben
        if (isnan(currentLightLux)) { // der Lichtsensor ist ausgefallen
            lamp1Relay.on(); // beide Lampen an
            lamp2Relay.on();
        } else { // der Lichtsensor funktioniert

            // TODO: Die Logik stimmt noch nicht!
            
            /*
            Strategie 1: Hysterese
            Es gibt zwei Schellen:
            * Einschalt-Schwelle (`THRESHOLD_DARK`): Bei dem bei ausgeschalteten Lampen das Tageslicht zu dunkel ist.
            * Ausschalt-Schwelle (`THRESHOLD_BRIGHT`): Bei dem bei eingeschalteten Lampen das Tageslicht zu hell ist. 
            */

            if (lamp1Relay.isOn() && lamp2Relay.isOn()) { // beide Lampen sind derzeit an
                if (currentLightLux > LIGHT_LUX_THRESHOLD_DARK) { // das Tageslicht ist mittel-hell
                    if (random(2) == 0) {// Zufällig eine Lampe ausschalten
                        lamp1Relay.off(); 
                    } else {
                        lamp2Relay.off();
                    }
                }
            } 
            else if (lamp1Relay.isOn() || lamp2Relay.isOn()) { // nur eine Lampe ist derzeit an
                if (currentLightLux > LIGHT_LUX_THRESHOLD_BRIGHT) { // das Tageslicht ist sehr hell
                    lamp1Relay.off(); // beide Lampen ausschalten
                    lamp2Relay.off();
                }
                // Bedingung zum Zuschalten von Lampe 2 (wenn es wieder dunkler wird)
                else if (currentLightLux < LIGHT_LUX_THRESHOLD_DARK) { // das Tageslicht ist dunkler
                    lamp1Relay.on(); // beide Lampen einschalten
                    lamp2Relay.on();
                }
            }
            else { // beide Lampen sind derzeit aus
                if (currentLightLux < LIGHT_LUX_THRESHOLD_BRIGHT) { // das Tageslicht ist nicht sehr hell
                    if (random(2) == 0) {// Zufällig eine Lampe einschalten
                        lamp1Relay.on(); 
                    } else {
                        lamp2Relay.on();
                    }
                }
                if (currentLightLux < LIGHT_LUX_THRESHOLD_DARK) { // das Tageslicht ist dunkel
                    lamp1Relay.on();
                    lamp2Relay.on();
                }
            }
        }
    } else {
        // Außerhalb des Zeitfensters: Beide Lampen sind immer aus, egal wie dunkel es ist.
        lamp1Relay.off();
        lamp2Relay.off();
    }

    /*
    Strategie 2 für die Lichtsteuerung: Verzögerung (Trägheit einbauen)

    Diese Strategie verhindert, dass das System auf kurzfristige Schwankungen (z.B. eine schnell vorbeiziehende Wolke) überreagiert.

    **Die Idee:** Eine Lampe wird erst dann an- oder ausgeschaltet, wenn der Schwellwert für eine **bestimmte Zeit** (z.B. 5 Minuten) ununterbrochen über- oder unterschritten wurde.

    **Wie du das umsetzen würdest:**
    Du bräuchtest zusätzliche globale Variablen, z.B. `unsigned long timeThresholdWasCrossed = 0;`.
    In `handleControlLogic` würdest du dann:
    1. Prüfen, ob `currentLightLux` über einer Schwelle liegt.
    2. Wenn ja, und `timeThresholdWasCrossed` ist `0`, setze `timeThresholdWasCrossed = millis();`.
    3. Wenn `currentLightLux` wieder unter die Schwelle fällt, setze `timeThresholdWasCrossed` zurück auf `0`.
    4. Schalte die Lampe erst dann, wenn `timeThresholdWasCrossed > 0` UND `millis() - timeThresholdWasCrossed > 300000` (5 Minuten).
    */

    // -- Steuerung für den Heizer (A3) --

    if (currentSoilTemp < SOIL_TEMPERATUR_TARGET) { 
        heaterRelay.on(); 
    } 
    else if (currentSoilTemp > SOIL_TEMPERATUR_TARGET + 0.5f) { 
        heaterRelay.off(); 
    }

    // -- Steuerung für den Lüfter (A4) --

    if (currentAirTemp > AIR_TEMPERATUR_THRESHOLD_HIGH && !fanRelay.isOn()) {
        fanRelay.pulse(FAN_COOLDOWN_DURATION_MS);
    }

    // Steuerung für die Pumpe (A5)

    if (isWaterLevelOk && !pumpRelay.isOn()) {
        if (currentSoilMoisture < SOIL_MOISTURE_TARGET && currentSoilMoisture != -1) {
            pumpRelay.pulse(WATERING_DURATION_MS);
        }
    }

    // -- Steuerung für den Vernebler (A6) --
    
    if (isWaterLevelOk) {
        if (currentHumidity < HUMIDITY_TARGET) { 
            misterRelay.on(); 
        } 
        else if (currentHumidity > HUMIDITY_TARGET + 5.0f) { 
            misterRelay.off(); 
        }
    } else {
        misterRelay.off();
    }
}

/**
 * @brief Nimmt ein Bild auf und speichert es auf der SD-Karte.
 */
void handleCamera() {
    Serial.println("Führe Kameraaufnahme aus...");
    display.showFullscreenAlert("FOTO...", false);

    char filename[30];
    sprintf(filename, "/img_%lu.jpg", millis());

    // KORREKTUR: Die neue Methode der sdCard-Klasse verwenden
    File imgFile = sdCard.openFileForWriting(filename);
    if (!imgFile) {
        Serial.println("Konnte Datei auf SD-Karte nicht erstellen.");
        display.showFullscreenAlert("SD FEHLER", true);
        delay(2000);
        return;
    }

    // Bild aufnehmen und direkt in die Datei streamen
    if (camera.captureAndStreamTo(ArduCamMini2MPPlusOV2640::S_1600x1200, imgFile)) {
        Serial.printf("Bild erfolgreich gespeichert: %s\n", filename);
        display.showFullscreenAlert("FOTO OK", false);
    } else {
        Serial.println("Fehler bei der Bildaufnahme.");
        display.showFullscreenAlert("KAMERA FEHLER", true);
    }

    imgFile.close();
    delay(2000);
}

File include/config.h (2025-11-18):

#pragma once 

/**
 * Zentrale Konfigurationsdatei für das Biodom Mini Projekt.
 */

// ------------------------------------------------------------
// GPIO-Pins für Sensoren, Aktoren und Peripheriegeräte
// ------------------------------------------------------------

// Sensoren
constexpr int PIN_AIR_SENSOR = 13;              // GPIO-Pin für den Raumtemperatur- und Luftfeuchtigkeitssensormodul AM2302 (S2)
constexpr int PIN_SOIL_TEMPERATUR_SENSOR = 4;   // GPIO-Pin für den Bodentemperatursensor DS18B20 (S3)
constexpr int PIN_SOIL_MOISTURE_SENSOR = 34;    // GPIO-Pin für den // Kapazitiver Bodenfeuchtigkeitssensor v1.2 (S4)
constexpr int PIN_WATER_LEVEL_SENSOR = 35;      // GPIO-Pin für den Füllstandsensor XKC-Y25-NPN (S5)

// I2C-Geräte (Kamera, Display und Lichtsensor GY-302 BH1750 (S6)
constexpr int PIN_I2C_SDA = 21;         // GPIO-Pin für I2C SDA (Data) Leitung
constexpr int PIN_I2C_SCL = 22;         // GPIO-Pin für I2C SCL (Clock) Leitung

// SPI-Geräte (Kamera und SD-Karte)
constexpr int PIN_SPI_MOSI = 23;        // GPIO-Pin für SPI MOSI Leitung
constexpr int PIN_SPI_MISO = 19;        // GPIO-Pin für SPI MISO Leitung
constexpr int PIN_SPI_SCK = 18;         // GPIO-Pin für SPI Clock Leitung
constexpr int PIN_SPI_SD_CS = 16;        // GPIO-Pin für SPI Chip Select der SD-Karte
constexpr int PIN_SPI_CAMERA_CS = 17;   // GPIO-Pin für SPI Chip Select der Kamera

// Aktoren
constexpr int PIN_LAMP1_RELAY = 14;     // GPIO-Pin für das Relais der Pflanzenlampe 1 (A1)
constexpr int PIN_LAMP2_RELAY = 27;     // GPIO-Pin für das Relais der Pflanzenlampe 2 (A2)
constexpr int PIN_HEATER_RELAY = 26;    // GPIO-Pin für das Relais der Heizmatte (A3)
constexpr int PIN_FAN_RELAY = 25;       // GPIO-Pin für das Relais des Lüfters (A4)
constexpr int PIN_PUMP_RELAY = 33;      // GPIO-Pin für das Relais der Wasserpumpe (A5)
constexpr int PIN_MISTER_RELAY = 32;    // GPIO-Pin für das Relais des Luftbefeuchters (A6)

// Sonstige Peripheriegeräte
constexpr int PIN_DEBUG_LED = 5;        // GPIO-Pin für die Debug-LED

// ------------------------------------------------------------
// NTP (Network Time Protocol) 
// ------------------------------------------------------------

const char* NTP_SERVER = "pool.ntp.org";    // NTP-Server
const long  GMT_OFFSET = 3600;              // Mitteleuropäische Zeit (MEZ) = UTC+1 = 3600 Sekunden für Zeitzone "Berlin"
const int   DAYLIGHT_OFFSET = 3600;         // Sommerzeit (MESZ) = UTC+2, also zusätzliche 3600 Sekunden (Sommer-/Winterzeit wird automatisch umgestellt)

// ------------------------------------------------------------
// Kalibrierung
// ------------------------------------------------------------

// Bodenfeuchte
constexpr int SOIL_MOISTURE_ADC_DRY = 2500; // ADC-Wert, wenn der Sensor in der Luft hängt (komplett trocken)
constexpr int SOIL_MOISTURE_ADC_WET = 1100; // ADC-Wert, wenn der Sensor in Wasser getaucht ist (komplett nass)

// ------------------------------------------------------------
// Intervalle
// ------------------------------------------------------------

// Sensoren lesen
constexpr unsigned long SENSOR_READ_INTERVAL = 5000;    // alle 5 Sekunden (in ms)

// Display aktualisieren
constexpr unsigned long DISPLAY_UPDATE_INTERVAL = 1000; // jede Sekunde (in ms)

// Kamera auslösen
constexpr unsigned long CAMERA_CAPTURE_INTERVAL = 3600000; // alle 60 Minuten (in ms)

// ------------------------------------------------------------
// Steuerungsparameter
// ------------------------------------------------------------

// Raumtemperatur (S1)
constexpr float AIR_TEMPERATUR_THRESHOLD_HIGH = 28.0; // Oberhalb dieser Temperatur (°C) wird der Lüfter eingeschaltet

// Luftfeuchtigkeit (S1)
constexpr float HUMIDITY_TARGET = 48.0; // Zielwert für Luftfeuchtigkeit (%), steuert Befeuchter

// Bodentemperatur (S2)
constexpr float SOIL_TEMPERATUR_TARGET = 19.0; // Zielwert für Bodentemperatur

// Bodenfeuchte (S3)
constexpr int SOIL_MOISTURE_TARGET = 50; // Zielwert für Bodenfeuchte in Prozent

// Wasserstand (S4)
constexpr bool WATER_LEVEL_TRIGGERED = false; // LOW/false = Wasser erkannt

// Betriebszeit für Lampen (A1 und A2)
constexpr int LIGHT_ON_HOUR = 8;    // Stunde, 0-23: Ab wann soll die Lampe angehen?
constexpr int LIGHT_OFF_HOUR = 17;  // Stunde, 0-23: Ab wann soll die Lampe ausgehen?

// Schwellwerte für Lichtsensor (S5), dass selbst in der Licht-An-Zeit eine oder beide Lampen aus bleiben dürfen 
constexpr float LIGHT_LUX_THRESHOLD_DARK   = 5.0f;  // Lux-Wert: ist das Tageslicht heller, bleibt eine Lampe aus
constexpr float LIGHT_LUX_THRESHOLD_BRIGHT = 15.0f; // Lux-Wert: ist das Tageslicht heller, bleiben beide Lampen aus

// Laufzeit des Lüfters (A4)
constexpr unsigned long FAN_COOLDOWN_DURATION_MS = 300000;  // 5 Minuten (in ms)

// Dauer der Bewässerung (A5)
constexpr unsigned long WATERING_DURATION_MS = 5000; // 5 Sekunden (in ms)

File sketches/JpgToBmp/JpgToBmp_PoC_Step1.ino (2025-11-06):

/**
 * PoC Schritt 1: Anzeige eines extern konvertierten JPGs auf dem OLED.
 * 
 * -- Das Ziel --
 * Validieren, dass der Konvertierungsprozess mit einem XBM-Tool funktioniert und das Ergebnis korrekt auf dem 
 * Display angezeigt werden kann.
 * 
 * -- Der Code --
 * Ich habe den Demo-Sketch für das OLED-Display genommen und alles bis auf das absolut Notwendigste entfernt. 
 *
 * -- Das Test-Bitmap --
 * Ich habe mein Portrait auf 128x64 Pixel skaliert (siehe `docs/assets/frank_128x64.jpg`), mit dem Tool 
 * "Online Image Converter to XBM" (https://www.online-utility.org/image/convert/to/XBM) in ein monochromes 
 * XBM-Bitmap umgewandelt und als C-Array exportiert. Danach habe ich drei kleine Verbesserungen vorgenommen:
 * 1. Ich habe die automatisch generierten Namen (`1762397827716_...`) in `portrait_...` umbenannt. 
 *    Das ist lesbarer und vermeidet potenzielle Compiler-Fehler, da Bezeichner in C++ nicht 
 *    mit einer Ziffer beginnen sollten.
 * 2. Ich habe `static char` in `static const unsigned char` geändert. Das ist der korrekte Datentyp  
 *    für rohe Bytedaten und `const`, weil sich die Daten nicht ändern.
 * 3. Ich habe das `U8X8_PROGMEM`-Makro hinzugefügt. Das ist eine gute Praxis, die der U8g2-Bibliothek 
 *    signalisiert, dass diese großen Daten im Flash-Speicher bleiben sollen und nicht den RAM des 
 *    Mikrocontrollers belegen.
 */

#include <Arduino.h>
#include <U8g2lib.h>

#ifdef U8X8_HAVE_HW_SPI
#include <SPI.h>
#endif
#ifdef U8X8_HAVE_HW_I2C
#include <Wire.h>
#endif

// --- Display-Initialisierung ---
// Ich verwende die bekannte Konfiguration für das SH1106 I2C Display.
U8G2_SH1106_128X64_NONAME_F_HW_I2C u8g2(U8G2_R0, /* reset=*/ U8X8_PIN_NONE);

// --- Das Test-Bitmap  im XBM-Format (konvertiert aus dem auf 128x64 skalierten JPG) ---
// XBM (X BitMap) ist ein Standard-C-Format, um monochrome Bilder zu speichern.
// Jedes Byte repräsentiert 8 horizontale Pixel. Die Bits werden "rückwärts" gelesen,
// d.h. das niedrigstwertige Bit (LSB) ist das linkeste Pixel.
#define portrait_width 128
#define portrait_height 64
static const unsigned char portrait_bits[] U8X8_PROGMEM = {
  0x00, 0x00, 0x00, 0xFE, 0xFF, 0x3B, 0xEE, 0x63, 0x4B, 0x00, 0x00, 0x00, 
  0x00, 0x00, 0x00, 0x00, 0x00, 0x00, 0x00, 0xFF, 0xFF, 0x97, 0x5E, 0x0A, 
  0x00, 0x00, 0x00, 0x00, 0x00, 0x00, 0x00, 0x00, 0x00, 0x00, 0x80, 0xDF, 
  0xFD, 0x6B, 0xA7, 0x99, 0x0A, 0x00, 0x00, 0x00, 0x00, 0x00, 0x00, 0x00, 
  0x00, 0x00, 0x80, 0x7F, 0xF3, 0xBC, 0x5B, 0x64, 0x01, 0x00, 0x00, 0x00, 
  0x00, 0x00, 0x00, 0x00, 0x00, 0x00, 0x80, 0x5F, 0xFD, 0xF5, 0x9F, 0xAA, 
  0x00, 0x00, 0x00, 0x00, 0x00, 0x00, 0x00, 0x00, 0x00, 0x00, 0xC0, 0xFF, 
  0xA6, 0xBB, 0x62, 0x56, 0x09, 0x00, 0x00, 0x00, 0x00, 0x00, 0x00, 0x00, 
  0x00, 0x00, 0xC0, 0xBF, 0xFE, 0xBD, 0xAB, 0xAF, 0x00, 0x00, 0x00, 0x00, 
  0x00, 0x00, 0x00, 0x00, 0x00, 0x00, 0xC0, 0x7F, 0x95, 0x8B, 0xDE, 0x6B, 
  0x02, 0x00, 0x00, 0x00, 0x00, 0x00, 0x00, 0x00, 0x00, 0x00, 0xC0, 0x7F, 
  0xAD, 0x87, 0xB7, 0xBF, 0x01, 0x00, 0x00, 0x00, 0x00, 0x00, 0x00, 0x00, 
  0x00, 0x00, 0xE0, 0x7F, 0xC9, 0x76, 0xFF, 0x7F, 0x00, 0x00, 0x00, 0x00, 
  0x00, 0x00, 0x00, 0x00, 0x00, 0x00, 0xE0, 0xFF, 0x5E, 0xEB, 0xFF, 0x7F, 
  0x00, 0x00, 0x00, 0x00, 0x00, 0x00, 0x00, 0x00, 0x00, 0x00, 0xC0, 0xFF, 
  0xA3, 0xF5, 0xFF, 0x7F, 0x00, 0x00, 0x00, 0x00, 0x00, 0x00, 0x00, 0x00, 
  0x00, 0x00, 0xE0, 0xF7, 0x3E, 0xF7, 0xFF, 0x7F, 0x00, 0x00, 0x00, 0x00, 
  0x00, 0x00, 0x00, 0x00, 0x00, 0x00, 0xE0, 0xDF, 0xA9, 0xFC, 0xFF, 0xA6, 
  0x02, 0x00, 0x00, 0x00, 0x00, 0x00, 0x00, 0x00, 0x00, 0x00, 0xE0, 0xFF, 
  0x5B, 0xFD, 0xBF, 0x3B, 0x00, 0x00, 0x00, 0x00, 0x00, 0x00, 0x00, 0x00, 
  0x00, 0x00, 0xD0, 0xB7, 0x9D, 0xFE, 0x7F, 0x08, 0x00, 0x00, 0x00, 0x00, 
  0x04, 0x00, 0x00, 0x00, 0x00, 0x00, 0xF0, 0xDF, 0xD5, 0xFF, 0x6F, 0x08, 
  0x00, 0x00, 0x00, 0x00, 0x01, 0x00, 0x00, 0x00, 0x00, 0x00, 0xF0, 0xFF, 
  0xFD, 0xFF, 0x0F, 0x00, 0x00, 0x00, 0x00, 0x00, 0x00, 0x00, 0x00, 0x00, 
  0x00, 0x00, 0xF8, 0xFF, 0xFE, 0xFF, 0x17, 0x00, 0x00, 0x00, 0x00, 0x00, 
  0x00, 0x00, 0x00, 0x00, 0x00, 0x00, 0xF0, 0xCF, 0xFD, 0xFF, 0x59, 0x01, 
  0x00, 0x00, 0x00, 0x00, 0x00, 0x00, 0x00, 0x00, 0x00, 0x00, 0xF8, 0xBF, 
  0xFF, 0xFF, 0x2B, 0x00, 0x00, 0x00, 0x02, 0x00, 0x00, 0x00, 0x00, 0x00, 
  0x00, 0x00, 0xF0, 0xFF, 0xFF, 0xFF, 0x17, 0x00, 0x00, 0x40, 0x00, 0x00, 
  0x04, 0x00, 0x00, 0x00, 0x00, 0x00, 0xF0, 0xFF, 0xFF, 0xFF, 0x56, 0x00, 
  0x00, 0x40, 0x0A, 0x00, 0x07, 0x00, 0x00, 0x00, 0x00, 0x00, 0xF0, 0xFF, 
  0xFF, 0xFF, 0x2F, 0x00, 0x00, 0xAC, 0x00, 0x80, 0x04, 0x00, 0x00, 0x00, 
  0x00, 0x00, 0xF0, 0xFF, 0xFF, 0xFF, 0x17, 0x00, 0xA0, 0x3A, 0x09, 0xC0, 
  0x08, 0x00, 0x00, 0x00, 0x00, 0x00, 0xE0, 0xFF, 0xFF, 0xFF, 0x6F, 0x02, 
  0x00, 0x41, 0x10, 0xC0, 0x01, 0x00, 0x00, 0x00, 0x00, 0x00, 0x40, 0xFF, 
  0xFF, 0xFF, 0x1F, 0x00, 0x40, 0x61, 0x45, 0xE1, 0x02, 0x00, 0x00, 0x00, 
  0x00, 0x00, 0x40, 0xFF, 0xFF, 0xFF, 0x3F, 0x00, 0x10, 0x00, 0x3C, 0x80, 
  0x00, 0x00, 0x00, 0x00, 0x00, 0x00, 0x80, 0xFE, 0xFF, 0xFF, 0x1F, 0x00, 
  0x15, 0x90, 0xF7, 0x01, 0x01, 0x00, 0x00, 0x00, 0x00, 0x00, 0x80, 0xFF, 
  0xFF, 0xFF, 0x6F, 0x18, 0x08, 0xE0, 0x6F, 0x01, 0x00, 0x00, 0x00, 0x00, 
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
};
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

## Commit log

2025-11-03 Weitere Sensoren hinzugefügt.
2025-11-06 Lib für Kamera, SD.Karte und Display hinzugefügt
2025-11-10 Libs für alle Sensoren
    [Labels.xlsx]
